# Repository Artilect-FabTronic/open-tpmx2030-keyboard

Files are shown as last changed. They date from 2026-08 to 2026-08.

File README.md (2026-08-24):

# open-tpmx2030-keyboard

Bienvenue sur le dépôt du projet de clavier BEPO `open-tpmx2030-keyboard` du FabLab Artilect.

Inspirée par la [présentation du projet ToucheLibre faite par Lilian Tribouilloy le 9 mars 2020 au fablab Artilect](https://touchelibre.fr/index.php/presentation-projet-en-video/) de Toulouse pendant l’une des soirées SuperLundi.

Ce projet a pour objectif de concevoir un clavier mécanique open source simple, basé sur le modèle de [clavier TypeMatrix 2030](https://typematrix.com/fr/products/2030/), avec des touches Cherry MX2A et des keycaps personnalisables.

Pour plus de détails sur la disposition bépo, veuillez consulter le wiki : <https://bepo.fr/wiki/TypeMatrix>

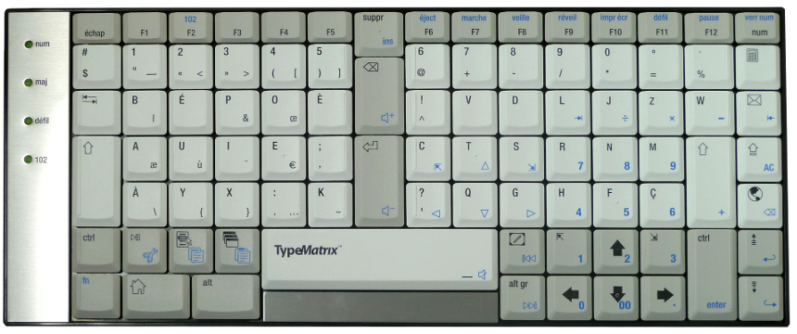
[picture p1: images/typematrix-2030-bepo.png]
TypeMatrix 2030 Bépo layout


---

## Contribuer au projet

Afin de permettre à chacun de contribuer à la version 1.0.0 du clavier `open-tpmx2030-keyboard`, merci de respecter la règle de nommage des branches et de ne pas commiter directement sur la branche main. En effet, la branche main est protégée et toute contribution doit passer par une pull request.

Un grand merci à tous les futurs contributeurs qui participeront à ce projet et qui continueront à le faire évoluer.

---

## Organisation du projet

Le présent fichier `README.md` est le point d'entrée du projet.

Le projet est structuré en différentes branches de la manière suivante :

- `feature/pcb` : contient les fichiers de conception du PCB du clavier.
- `feature/firmware` : contient le firmware du clavier.

Le dossier [`*/docs/`](./docs/README.md) : contient la documentation du projet.

Voir les bonnes pratiques pour les messages de commit : <https://commitizen-tools.github.io/commitizen/tutorials/writing_commits/>

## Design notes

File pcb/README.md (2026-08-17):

# 🛠️ Guide de Conception KiCad — Projet Open-TPMX2030

Ce guide est destiné aux membres et hackers du FabLab Artilect participant au développement de la carte électronique (PCB) du clavier ergonomique Open-TPMX2030.

Il regroupe les règles de l'art en ingénierie électronique pour concevoir un PCB propre, robuste, facile à fabriquer (JLCPCB / PCBWay) et à déboguer.

---

## 📌 1. Structure du Projet & Conventions de Nommage

Editer le fichier `.kicad_pro` avec un éditeur de texte est modifier la section `text_variables` en fin du fichier avec les éléments suivants :

```plaintext
  "text_variables": {
    "COMPANY": "Copyright (c) 2026 Artilect FabLab Toulouse",
    "CREATION_DATE": "2026-08-16",
    "LICENSE": "Apache-2.0 license",
    "PROJECT_NAME": "Open-TPMX2030 keyboard",
    "REVISION": "1.0.0",
    "SERIAL_NUM": "S/N: 260816-Artilect-P001",
    "USER_EMAIL": "arnauld.biganzoli@gmail.com",
    "USER_NAME": "ArnauldDev"
  },
```

Et depuis l'édition des fichiers `.kicad_sch` et `.kicad_pcb`, compléter la section `title_block` avec les éléments suivants :

```plaintext
	(title_block
		(title "${PROJECT_NAME}")
		(date "${CREATION_DATE}")
		(rev "${REVISION}")
		(company "${COMPANY}")
		(comment 1 "License: ${LICENSE}")
		(comment 2 "${USER_EMAIL}")
		(comment 3 "${USER_NAME}")
		(comment 4 "Electrical CAD Operator:")
	)
```

### 1.1 Organisation du Dépôt Git

Tout le projet Hardware réside dans le dossier `/pcb` du dépôt GitHub `open-tpmx2030-keyboard`.

```plaintext
├── pcb/
│   ├── open_tpmx2030.kicad_pro       # Fichier projet KiCad
│   ├── open_tpmx2030.kicad_sch       # Schématique racine (Feuille Principale)
│   ├── open_tpmx2030.kicad_pcb       # Layout du PCB
│   ├── open_tpmx2030.kicad_dru       # Règles de routage personnalisées (DRC)
│   ├── mcu_rp2040.kicad_sch          # Module Microcontrôleur RP2040-Zero
│   ├── matrix_expanders.kicad_sch    # Module MCP23017 (I2C)
│   ├── key_matrix.kicad_sch          # Matrice de switches (keyboard 102 touches + diodes)
│   ├── user_interface.kicad_sch      # Encodeurs + LEDs
│   └── libraries/                    # Symboles et Empreintes spécifiques
│       ├── symbols/                  # .kicad_sym (.kicad_sym)
│       ├── footprints/               # .kicad_mod (.pretty)
│       └── 3dmodels/                 # Modèles 3D (.3dshapes, .stp)
└── manufacturing/                    # Gerbers, Drill, BOM, CPL (Générés)
```

### 1.2 Règles de nommage des composants

Pour s'y retrouver facilement lors du soudage manuel ou de l'inspection :

* U1, U2, ... : Circuits intégrés (RP2040, MCP23017)
* SW1 à SW102 : Switches de touches (Cherry MX2A)
* SW_ENC1 à SW_ENC3 : Switches d'encodeurs rotatifs
* D1 à D102 : Diodes de matrice (1N4148 / SOD-123)
* LED1 à LED4 : LEDs d'état (0805)
* R1, R2, ... : Résistances
* C1, C2, ... : Condensateurs
* ENC1 à ENC3 : Encodeurs rotatifs (EC11)

---

## 📐 2. La schématique (Eeschema)

### 2.1 Approche par Schémas Hiérarchiques

Ne mettez jamais l'intégralité d'un projet de 102 touches sur une seule page géante !

Utilisez des Feuilles Hiérarchiques (Hierarchical Sheets) :

1. Racine (open_tpmx2030.kicad_sch) : Bloc-diagramme reliant les sous-modules via des labels hiérarchiques (Bus I2C, INT, Power).
2. Feuille mcu_rp2040 : RP2040-Zero, régulateur de tension (si besoin), filtrage d'alimentation, connecteur USB-C.
3. Feuille matrix_expanders : Les 2x MCP23017, adresses I2C (A0, A1, A2), résistances de tirage I2C (Pull-up).
4. Feuille key_matrix : Matrice $8 \times 13$ réparties proprement en sous-ensembles (ex: réplication de blocs).
5. Feuille user_interface : 3 Encodeurs EC11 + 4 LEDs.

### 2.2 Bonnes Pratiques de Schématique

* **Sens de lecture :** Les signaux d'entrée viennent de la **gauche**, les sorties vont vers la **droite**, les alimentations ($V_{CC}$ / $+3.3\text{V}$) sont en **haut**, et les masses ($\text{GND}$) sont en **bas**.
* **Condensateurs de découplage :** Dessinez TOUJOURS les condensateurs de découplage ($100\text{ nF}$) à côté des broches d'alimentation des puces correspondantes (`VCC/VDD` du MCP23017, etc.) sur le schéma, pour rappeler qu'ils doivent être soudés au plus près en layout.
* **Net Labels clairs :** Utilisez des noms de réseaux explicites (`I2C_SDA`, `I2C_SCL`, `ROW_0`, `COL_12`, `ENC_VOL_CLK`).

---

## ⚡ 3. Les Règles de Routage PCB (Pcbnew)

### 3.1 Empilement de la Carte (Layer Stackup - 2 Couches)

Puisqu'il s'agit d'une carte 2 couches classique (1.6 mm FR4, $35\ \mu\text{m}$ Cuivre) :

* Couche Supérieure (F.Cu - Red) : Signaux principaux, bus de données, matrice de touches.
* Couche Inférieure (B.Cu - Blue) : Plan de Masse Continu ($\text{GND}$).
  * _Règle absolue :_ Évitez au maximum de couper le plan de masse face inférieure avec de longues pistes. Si une piste doit passer en `B.Cu`, faites un "pont" court et revenez en `F.Cu`.

### 3.2 Largeur de Pistes (Track Widths)

Configurons les classes de réseaux (Net Classes) dans KiCad :

| Classe de Réseau | Largeur de Piste | Isolation (Clearance) | Via (Perçage / Anneau) | Usage |
| --- | --- | --- | --- | --- |
| Default | $0.20\text{ mm}$ ($8\text{ mil}$)  | $0.20\text{ mm}$ ($8\text{ mil}$)  | $0.6\text{ mm} / 0.3\text{ mm}$ | Signaux matrice, LEDs, GPIOs |
| HighSpeed_I2C | $0.25\text{ mm}$ ($10\text{ mil}$) | $0.25\text{ mm}$ ($10\text{ mil}$) | $0.6\text{ mm} / 0.3\text{ mm}$ | Bus I2C (SDA / SCL à 1 MHz) |
| Power (+3.3V) | $0.50\text{ mm}$ ($20\text{ mil}$) | $0.25\text{ mm}$ ($10\text{ mil}$) | $0.8\text{ mm} / 0.4\text{ mm}$ | Lignes d'alimentation principal |
| Power (+5V USB)  | $0.75\text{ mm}$ ($30\text{ mil}$) | $0.30\text{ mm}$ ($12\text{ mil}$) | $0.8\text{ mm} / 0.4\text{ mm}$ | VBUS d'entrée USB |

### 3.3 Placement des Composants

1. **Positionnement Ergonomique (Fixe) :** Placez d'abord les switches MX2A (espacement standard $19.05\text{ mm} \times 19.05\text{ mm}$ ou selon le layout spécifique TypeMatrix), les 3 encodeurs et les 4 LEDs.
2. **Zone Microcontrôleur & Expanders :** Placez le RP2040-Zero et les 2x MCP23017 dans la partie supérieure de la carte.
3. **Condensateurs de découplage ($100\text{ nF}$) :** Placer IMPÉRATIVEMENT chaque condensateur de découplage à moins de $2\text{ mm}$ de la broche $V_{DD}$ du MCP23017, relié directement au plan de masse par un via.

---

## 🛡️ 4. Intégrité du Signal & Compatibilité Électromagnétique (CEM)

1. **Bus I2C à 1 MHz :**
  * Gardez les pistes I2C_SDA et I2C_SCL parallèles, de longueur similaire et le plus court possible entre le RP2040-Zero et les deux MCP23017.
  * Placez les résistances de tirage ($R_{pullup} = 2.2\text{ k}\Omega$) près du RP2040-Zero.
2. **Diodes Anti-Ghosting :**
  * Chaque touche contient une diode 1N4148 (boîtier SOD-123). Placez la diode juste à côté du pad du switch correspondant pour garder un routage ultra-propre et compact.
3. **Vias de Masse (Via Stitching) :**
  * Distribuez généreusement des vias de masse autour du microcontrôleur et le long du contour de la carte pour assurer une excellente continuité du plan de masse GND.

---

## 🔍 5. Liste de Contrôle Avant Fabrication (Checklist DRC)

Avant de générer les fichiers Gerber pour le FabLab ou l'usine :

- [ ] Lancer le DRC (Design Rules Check) : 0 erreur, 0 avertissement toléré.
- [ ] Contrôle d'empreintes (Footprints) : Vérifier le sens des diodes (Cathode / Anode) et l'orientation du RP2040-Zero.
- [ ] Trous de Fixation (Mounting Holes) : Placer des trous $M3$ (non métallisés ou reliés à la masse) aux 4 coins et au centre pour la rigidité lors de la frappe.
- [ ] Visualisation 3D (Alt + 3) : Vérifier qu'aucun composant ne se chevauche (notamment les corps des switches MX2A et les encodeurs EC11).
- [ ] Sérigraphie (Silkscreen) :
  * Nom du projet : Open-TPMX2030 (FabLab Artilect)
  * Version du PCB : v1.0.0 - 2026
  * Logos : Logo Open Source Hardware + Logo Artilect.
  * Indication lisible des LEDs (NUM/FN, CAPS, SCROLL, DVORAK) et des fonctions des encodeurs (LUM, MIC, VOL).

---

## 📦 6. Export pour la Fabrication

Exportez depuis KiCad dans le dossier `/production` :

1. **Fichiers Gerber (RS-274X) :** Couches `F.Cu`, `B.Cu`, `F.Silkscreen`, `B.Silkscreen`, `F.Mask`, `B.Mask`, `Edge.Cuts` (Contour).
2. **Fichier de Perçage (Excellon / NC Drill) :** Unités en mm, coordonnées absolues.
3. **Fichiers de Placement SMT (Position / CPL) :** Fichier `.csv` pour l'assemblage automatique des composants de surface (Diodes SOD-123, MCP23017, Résistances 0805).

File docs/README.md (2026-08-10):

# Documentation Technique — Open-TPMX2030

> Étude technique du projet de conception du clavier **Open-TPMX2030**  
> *(Open Source TypeMatrix Mechanical Edition)*  
> Projet du FabLab **Artilect** — Toulouse

---

## Table des matières

| N°  | Document | Description |
| --- | --- | --- |
| — | [Présentation du projet](./01-presentation-projet.md) | Genèse, objectifs, organisation du dépôt  |
| — | [Conception Hardware & PCB](./02-conception-hardware.md) | MCU, matrice de touches, BOM, pinout |
| — | [Interface Homme-Machine (IHM)](./03-interface-ihm.md) | Encodeurs rotatifs, LEDs, keycaps |
| — | [Architecture Firmware](./04-firmware-architecture.md) | Code C++/Arduino, HID, scancodes |
| — | [Analyse GPIO & Extension I2C](./05-analyse-gpio-extension.md) | MCP23017 vs 74HC165, architecture retenue |
| — | [Dispositions Clavier](./06-dispositions-clavier.md) | Bépo, Dvorak, QWERTY, outils logiciels |
| — | [Ressources & Références](./07-ressources-references.md) | Datasheets, liens, fournisseurs, projets  |

---

## Architecture Globale du Projet

```mermaid
graph TD
    subgraph HARDWARE["🔧 Hardware (PCB)"]
        MCU["RP2040-Zero\n(ARM Cortex-M0+)"]
        MCP1["MCP23017 #1\n(Lignes - 0x20)"]
        MCP2["MCP23017 #2\n(Colonnes - 0x21)"]
        MATRIX["Matrice 8×13\n(102 switches + 1N4148)"]
        ENC["3× Encodeurs EC11\n(Luminosité / Micro / Volume)"]
        LEDS["4× LEDs SMD 0805\n(Num / Caps / Scroll / Dvorak)"]
    end

    subgraph FIRMWARE["💾 Firmware (Arduino / C++)"]
        SCAN["Scan Matrice I2C"]
        MAP["Mapping Scancodes\n(HID ↔ PS/2)"]
        HID["Rapport USB HID\n(Keyboard + Consumer)"]
        LAYOUTS["Couches de Layout\nQWERTY / Bépo / Dvorak"]
    end

    subgraph HOST["🖥️ Hôte USB"]
        USB["Port USB-C\n(HID Device)"]
        PC["Ordinateur"]
    end

    MCU -- "I2C 1 MHz\n(SDA/SCL GP2/GP3)" --> MCP1
    MCU -- "I2C 1 MHz" --> MCP2
    MCP1 -- "Port A (L0-L7)\nOUT" --> MATRIX
    MCP2 -- "Port A+B (C0-C12)\nIN Pull-up" --> MATRIX
    MCU -- "GP7-GP15\n(CLK/DT/SW)" --> ENC
    MCU -- "GP0, GP4-GP6" --> LEDS
    MCU -- "INT GP1\n(Wake-up)" --> MCP1

    SCAN --> MAP --> LAYOUTS --> HID
    MCU --> SCAN
    HID --> USB --> PC
```

---

## Résumé Technique Rapide

| Caractéristique | Valeur |
| --- | --- |
| **Microcontrôleur** | Waveshare RP2040-Zero (ARM Cortex-M0+ @ 133 MHz) |
| **Nombre de touches** | 102 touches (layout 102 Europe) |
| **Extension GPIO** | 2× MCP23017 sur bus I2C @ 1 MHz |
| **Latence scan matrice** | < 300 µs (invisible à la frappe) |
| **Switches V1** | Cherry MX2A Brown (Tactile) |
| **Switches V2** | Cherry MX2A Blue (Clicky) |
| **Anti-ghosting** | Full N-Key Rollover (NKRO) via diodes 1N4148 |
| **IHM** | 3 encodeurs EC11 + 4 LEDs d'état |
| **Firmware** | Arduino-Pico (Earle F. Philhower) |
| **Interface USB** | USB HID natif (Keyboard + Consumer Control) |
| **Layouts supportés** | QWERTY, Bépo, Dvorak, Colemak-DH |
| **Licence** | Apache-2.0 license (Open Source) |

---

## Image de référence du Layout

TypeMatrix 2030 Bépo layout

---

## Liens Rapides

- 🏠 [Dépôt GitHub principal](https://github.com/Artilect-FabTronic/open-tpmx2030-keyboard)
- 📋 [Wiki Bépo — TypeMatrix](https://bepo.fr/wiki/TypeMatrix)
- 🔌 [Datasheet RP2040](https://pip-assets.raspberrypi.com/categories/814-rp2040/documents/RP-008371-DS-1-rp2040-datasheet.pdf)
- 🔌 [Datasheet MCP23017](https://ww1.microchip.com/downloads/aemDocuments/documents/APID/ProductDocuments/DataSheets/MCP23017-MCP23S17-16-Bit-IO-Expander-with-Serial-Interface-DS20001952.pdf)
- 🛠️ [KiCad — Logiciel PCB](https://www.kicad.org/)
- ⌨️ [Configurateur Keycaps ThockFactory](https://thockfactory.com/fr/configurator)

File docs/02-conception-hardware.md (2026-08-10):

# 02 — Conception Hardware & PCB

> **Retour à l'index :** [Documentation](./README.md)

---

## Table des matières

- [Microcontrôleur — RP2040-Zero](#microcontrôleur--rp2040-zero)
- [Matrice de touches](#matrice-de-touches)
- [Switches Cherry MX2A](#switches-cherry-mx2a)
- [Assignation finale des broches GPIO](#assignation-finale-des-broches-gpio)
- [Architecture hardware globale](#architecture-hardware-globale)
- [Nomenclature BOM](#nomenclature-bom)
- [Outils de conception PCB](#outils-de-conception-pcb)

---

## Microcontrôleur — RP2040-Zero

### Pourquoi le RP2040 ?

Le **RP2040** de Raspberry Pi a été retenu comme cœur du projet pour les raisons suivantes :

- **Dual-core ARM Cortex-M0+** cadencé à 133 MHz — puissance largement suffisante pour la gestion d'un clavier complexe.
- **Support natif USB HID** : pas de circuit USB externe requis, le RP2040 gère lui-même le protocole USB Full Speed.
- **Écosystème open source vaste** : SDK C/C++, MicroPython, CircuitPython, Arduino-Pico.
- **Faible coût** (~3-5 € l'unité en lot).
- **Format castellated** du RP2040-Zero : permet de souder directement la carte sur le PCB principal.

### Caractéristiques techniques du RP2040-Zero (Waveshare)

| Caractéristique | Valeur |
| --- | --- |
| **Processeur** | ARM Cortex-M0+ dual-core @ 133 MHz |
| **SRAM** | 264 Ko |
| **Mémoire Flash** | 2 Mo (W25Q16 SOIC-8) |
| **GPIO accessibles** | 20 broches (GP0–GP15, GP26–GP29) |
| **Connectique** | USB-C |
| **Spécificité** | Format ultra-compact, castellated (soudable sur PCB) |
| **LED RGB intégrée** | WS2812B sur GPIO 16 |

### Ressources

- 📄 [Datasheet RP2040](https://pip-assets.raspberrypi.com/categories/814-rp2040/documents/RP-008371-DS-1-rp2040-datasheet.pdf)
- 📄 [Hardware Design with RP2040](https://pip-assets.raspberrypi.com/categories/814-rp2040/documents/RP-008279-DS-1-hardware-design-with-rp2040.pdf)
- 🌐 [Wiki Waveshare RP2040-Zero](https://www.waveshare.com/wiki/RP2040-Zero)
- 🔌 [Pinout TinyGo Reference](https://tinygo.org/docs/reference/microcontrollers/machine/waveshare-rp2040-zero/)

### Pinout et schématique de la carte RP2040-Zero

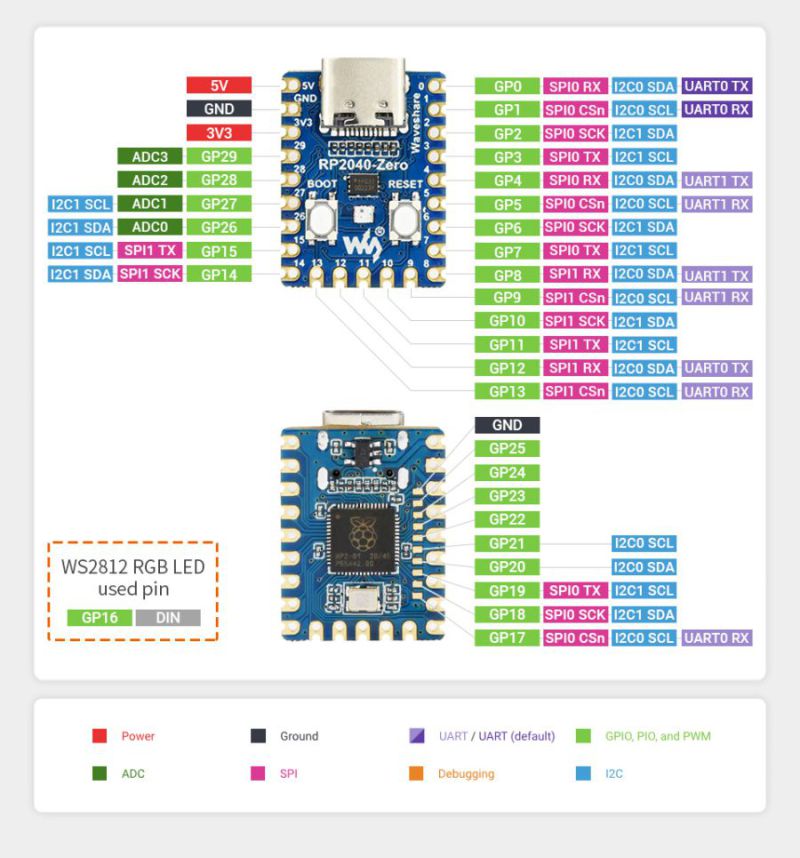
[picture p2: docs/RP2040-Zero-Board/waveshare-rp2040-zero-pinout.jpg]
Waveshare RP2040-Zero Pinout


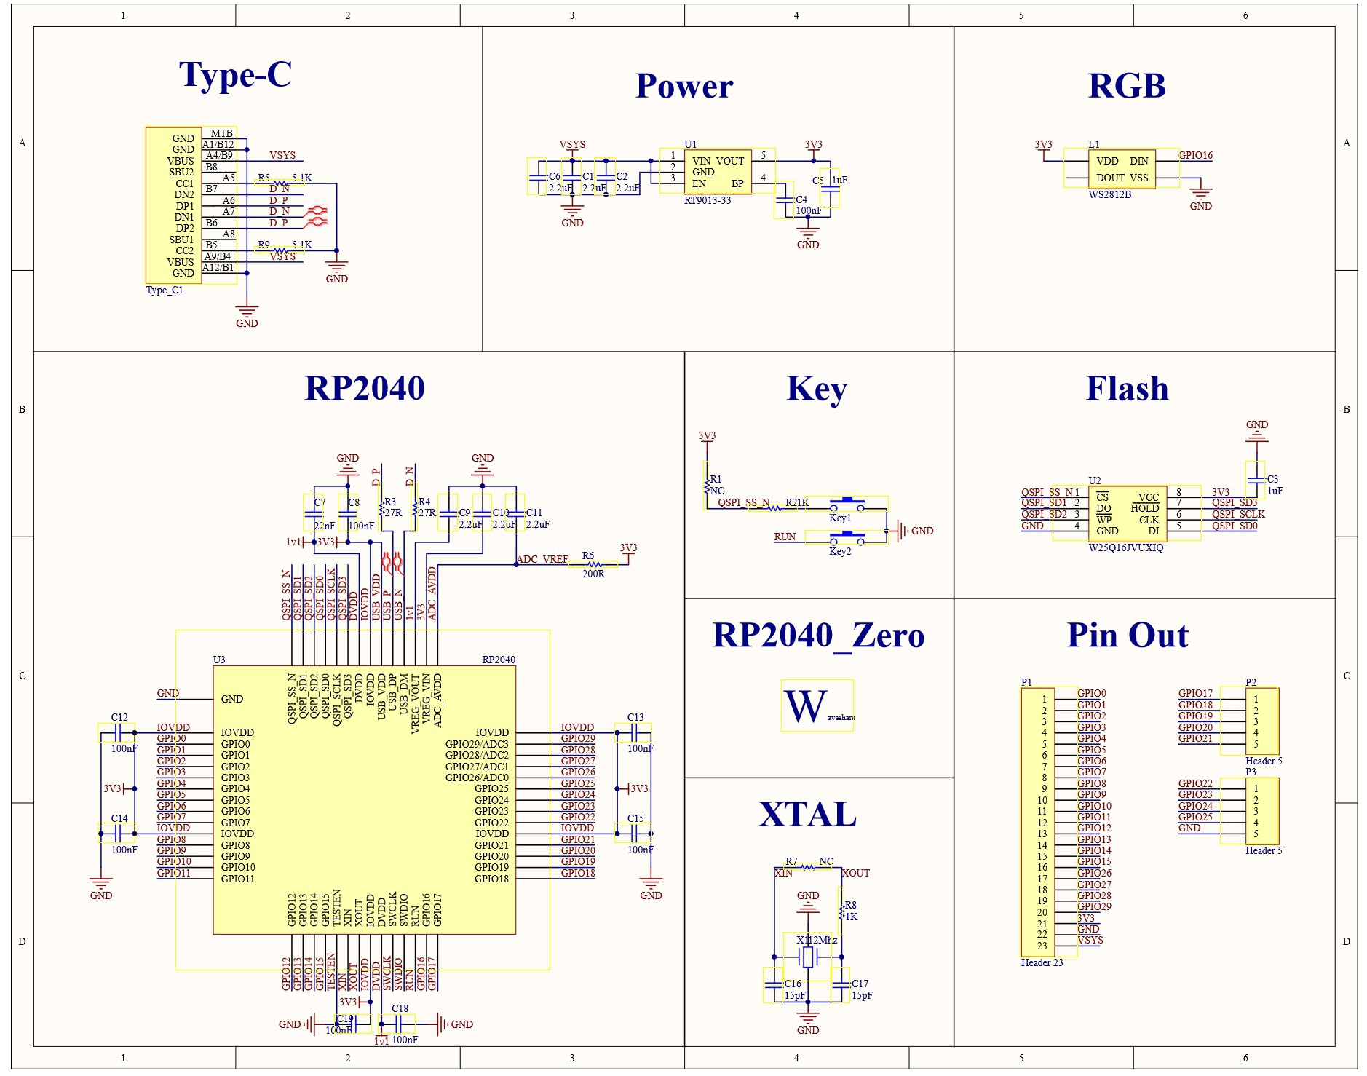
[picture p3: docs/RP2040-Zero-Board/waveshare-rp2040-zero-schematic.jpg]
Waveshare RP2040-Zero Schéma


### Options de programmation

| Environnement | Langage | Remarques |
| --- | --- | --- |
| **Arduino-Pico** (Earle Philhower) | C++ | Retenu pour ce projet — support HID natif |
| SDK officiel Raspberry Pi | C/C++ | Plus bas niveau, plus de contrôle |
| MicroPython | Python  | Moins adapté pour HID temps-réel |
| CircuitPython (Adafruit) | Python  | Bonne bibliothèque HID |

**Pour ajouter le support RP2040 dans Arduino IDE**

Additional Boards Manager URLs : `https://github.com/earlephilhower/arduino-pico/releases/download/global/package_rp2040_index.json`

---

## Matrice de touches

### Principe de la matrice

La matrice de touches est la solution standard pour connecter un grand nombre de touches avec un minimum de broches. Les touches sont organisées en **lignes** et **colonnes** ([vidéo](https://www.youtube.com/watch?v=dop0SoD2XL8)) :

- Une seule **ligne** est activée à la fois (mise à LOW).
- Toutes les **colonnes** sont lues simultanément.
- Une **diode par touche** (1N4148) évite le phénomène de *ghosting* (touches fantômes) et permet le **N-Key Rollover (NKRO)** — détection simultanée de toutes les touches.

### Dimensions de la matrice

Pour 102 touches, la topologie retenue est :

```
8 Lignes (Output) × 13 Colonnes (Input Pull-up) = 104 emplacements
```

> Les 2 emplacements non utilisés peuvent être réservés pour des touches supplémentaires futures.

### Diodes Anti-Ghosting

- **Référence :** 1N4148 (boîtier SOD-123 pour montage CMS)
- **Câblage :** Anode → Ligne, Cathode → Colonne (via le switch)
- **Effet :** Full N-Key Rollover — appui simultané de toutes les touches sans ambiguïté.

```
    Ligne (LOW)
        |
       [A]→[K]→[1N4148]→ Colonne (IN Pull-up)
       [A] = Anode diode
       [K] = Cathode diode
       [1N4148] = Diode
```

### Pourquoi pas de GPIO directs sur le RP2040 ?

Le RP2040-Zero n'expose que **20 broches GPIO**. Avec les périphériques déjà connectés (LEDs, encodeurs), il ne reste que **7 GPIO libres**, insuffisants pour piloter 21 lignes/colonnes. L'extension via **MCP23017** (I2C) est donc indispensable.

> Pour l'analyse complète de ce choix, voir : [05 — Analyse GPIO & Extension I2C](./05-analyse-gpio-extension.md)

---

## Switches Cherry MX2A

### Version V1 — Brown (Tactile)

- **Référence :** [Cherry MX2A Brown](https://www.cherry.de/en-gb/product/mx2a-brown)
- **Type :** Tactile, pré-lubrifié d'usine
- **Caractéristiques :** Frappe fluide et relativement silencieuse, retour tactile subtil
- **Usage recommandé :** Environnements de bureau, frappe intensive

### Version V2 — Blue (Clicky)

- **Référence :** [Cherry MX2A Blue](https://www.cherry.de/en-gb/product/mx2a-blue)
- **Type :** Clicky, retour tactile accentué avec clic sonore
- **Usage recommandé :** Utilisateurs appréciant le feedback sonore

### Sockets Hotswap

Recherche en cours d'un support de touche **soudable sur PCB** permettant l'échange des switches Cherry MX2A sans dessouder.

- Compatibilité : Cherry MX (standard 5mm stem spacing)
- Références à valider : Kailh PCB Socket, Mill-Max 0305 / 7305

> **Fournisseurs :** [RS-Online — Interrupteurs clavier](https://fr.rs-online.com/web/p/interrupteurs-de-clavier/0664569) | [Mouser — Cherry Electrical](https://www.mouser.fr/fr/manufacturer/cherry-electrical/)

---

## Assignation finale des broches GPIO

Cette table intègre l'ensemble des périphériques connectés au RP2040-Zero :

| Fonction | Pin RP2040-Zero | Direction  | Rôle |
| --- | --- | --- | --- |
| **I2C SDA** | GP2 | Bidir | Bus données I2C (MCP23017 #1 & #2) |
| **I2C SCL** | GP3 | OUT | Bus horloge I2C @ 1 MHz |
| **INT_KEYBOARD** | GP1 | IN Pull-up | Interruption matrice / Wake-Up sommeil |
| **LED 1 (Num/Fn)** | GP0 | OUT | LED état — Couleur bleue |
| **LED 2 (Caps)** | GP4 | OUT | LED Caps Lock |
| **LED 3 (Scroll)** | GP5 | OUT | LED Scroll Lock |
| **LED 4 (Dvorak)** | GP6 | OUT | LED Mode Dvorak |
| **Enc 1 CLK (Lum)** | GP7 | IN Pull-up | Luminosité — Signal horloge |
| **Enc 1 DT (Lum)** | GP8 | IN Pull-up | Luminosité — Signal direction |
| **Enc 1 SW (Lum)** | GP9 | IN Pull-up | Luminosité — Bouton poussoir |
| **Enc 2 CLK (Mic)** | GP10 | IN Pull-up | Microphone — Signal horloge |
| **Enc 2 DT (Mic)** | GP11 | IN Pull-up | Microphone — Signal direction |
| **Enc 2 SW (Mic)** | GP12 | IN Pull-up | Microphone — Bouton poussoir |
| **Enc 3 CLK (Vol)** | GP13 | IN Pull-up | Volume — Signal horloge |
| **Enc 3 DT (Vol)** | GP14 | IN Pull-up | Volume — Signal direction |
| **Enc 3 SW (Vol)** | GP15 | IN Pull-up | Volume — Bouton poussoir |
| **LED RGB (NeoPixel)** | GP16 | OUT | LED RGB intégrée (WS2812B) |
| **Disponibles** | GP26, GP27, GP28, GP29 | Libre | PWM rétroéclairage, extensions futures |

### Bilan GPIO

| Catégorie | GPIOs utilisées |
| --- | --- |
| Bus I2C (SDA + SCL)  | 2 |
| Interruption Wake-up | 1 |
| LEDs d'état | 4 |
| Encodeurs (3 × 3) | 9 |
| **Total utilisé** | **16 / 20** |
| **Libres** | **4 (GP26–GP29)** |

---

## Architecture hardware globale

```
                       RP2040-ZERO
                   +-----------------+
                   | GP2 (SDA) ------+----------> Bus I2C (SDA) + Pull-up 2.2kΩ
                   | GP3 (SCL) ------+----------> Bus I2C (SCL) + Pull-up 2.2kΩ
                   | GP1 (INT_WAKE) -+<---------- INTA (Combined Interrupt)
                   | GP0  (LED Num) -+----------> LED SMD 0805 Bleue
                   | GP4  (LED Caps)-+----------> LED SMD 0805
                   | GP5  (LED Scrl)-+----------> LED SMD 0805
                   | GP6  (LED Dvk) -+----------> LED SMD 0805
                   | GP7-9  (Enc 1) -+----------> Encodeur Luminosité EC11
                   | GP10-12 (Enc 2)-+----------> Encodeur Microphone EC11
                   | GP13-15 (Enc 3)-+----------> Encodeur Volume EC11
                   +-----------------+
                            |
           +----------------+----------------+
           |                                 |
  +-----------------+               +-----------------+
  |   MCP23017 #1   |               |   MCP23017 #2   |
  |  Adresse: 0x20  |               |  Adresse: 0x21  |
  +-----------------+               +-----------------+
  | Port A: Lignes  |               | Port A: Col 0-7 |
  | (L0 - L7) OUT   |               | Port B: Col 8-12|
  +-----------------+               +-----------------+
           |                                 |
           +------------ Matrice ------------+
                    (102 Switches + 1N4148)
                    8 Lignes × 13 Colonnes
```

---

## Nomenclature BOM

*Bill of Materials — Nomenclature préliminaire du projet*

| Désignation | Référence / Modèle | Qté | Boîtier | Remarques |
| --- | --- | ----- | --- | --- |
| **Microcontrôleur** | Waveshare RP2040-Zero  | 1 | Module | Format castellated, USB-C intégré |
| **Extenseur GPIO** | MCP23017-E/SS | 2 | SSOP-28 | Bus I2C, adresses 0x20 et 0x21 |
| **Mémoire Flash** | W25Q16 / W25Q32 | 1 | SOIC-8 | Embarquée sur le RP2040-Zero |
| **Switches Mec.** | Cherry MX2A Brown (V1) | ~102  | Traversant | V1 — Tactile |
| **Switches Mec.** | Cherry MX2A Blue (V2)  | ~102  | Traversant | V2 — Clicky |
| **Diodes Anti-Ghost.** | 1N4148W | ~102  | SOD-123 | 1 par switch — NKRO |
| **Encodeurs Rotatifs** | EC11 avec switch | 3 | Traversant | Luminosité, Micro, Volume |
| **LED Signalisation**  | LED SMD 0805 Bleue | 1 | 0805 | Num/Fn Lock |
| **LED Signalisation**  | LED SMD 0805 | 3 | 0805 | Caps, Scroll, Dvorak |
| **Connecteur USB** | USB Type-C Réceptacle  | 1 | SMD | Alimentation & Data HID |
| **Résistances I2C** | 2.2kΩ | 2 | 0402 | Pull-up SDA et SCL |
| **Condensateurs** | 100nF | ~10 | 0402 | Découplage alimentation |
| **Condensateurs** | 10µF | 2 | 0805 | Filtrage alimentation principale |
| **Keycaps Set** | Custom Ortholinear | 1 set | — | Marquages Bépo/Dvorak/QWERTY (ThockFactory) |
| **Sockets Hotswap** | Kailh PCB Socket (TBC) | ~102  | SMD | À confirmer — compatibilité Cherry MX |

---

## Outils de conception PCB

### KiCad

Le PCB est conçu sous [**KiCad**](https://www.kicad.org/) (version 10+), logiciel EDA open source.

- **Schématique (Schéma électrique)** : KiCad Schematic Editor (`.kicad_sch`)
- **PCB Layout** : KiCad PCB Editor (`.kicad_pcb`)
- **Empreintes Cherry MX** : disponibles dans les bibliothèques officielles KiCad ou via [github.com/blakesmith/embedded](https://github.com/blakesmith/embedded/tree/master/keebee/hardware)

```
Empreinte 3D switch Cherry MX :
${KISYS3DMOD}/Buttons_Switches_Keyboard.3dshapes/SW_Cherry_MX1A_1.00u_Plate.wrl
```

### Ergogen (Layout PCB automatisé)

[**Ergogen**](https://ergogen.xyz/new) est un outil web permettant de générer automatiquement la disposition physique des touches et le PCB à partir d'un fichier de configuration YAML. Particulièrement adapté aux claviers ortholinéaires.

---

> **Page précédente :** [01 — Présentation du projet](./01-presentation-projet.md)  
> **Page suivante :** [03 — Interface Homme-Machine (IHM)](./03-interface-ihm.md)

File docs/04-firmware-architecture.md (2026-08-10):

# 04 — Architecture Firmware

> **Retour à l'index :** [Documentation](./README.md)

---

## Table des matières

- [Choix de l'environnement de développement](#choix-de-lenvironnement-de-développement)
- [Boucle principale du firmware](#boucle-principale-du-firmware)
- [USB HID — Protocole et implémentation](#usb-hid--protocole-et-implémentation)
- [Traduction Scancodes USB HID ↔ PS/2](#traduction-scancodes-usb-hid--ps2)
- [Gestion des layouts alternatifs](#gestion-des-layouts-alternatifs)
- [Code source complet commenté](#code-source-complet-commenté)

---

## Choix de l'environnement de développement

### Arduino-Pico (Earle F. Philhower)

Le firmware est développé sous [**Arduino-Pico**](https://github.com/earlephilhower/arduino-pico) — le core Arduino non-officiel mais très complet pour le RP2040, maintenu par Earle F. Philhower.

**Pourquoi Arduino-Pico plutôt que QMK ou ZMK ?**

| Critère | Arduino-Pico | QMK | ZMK |
| --- | --- | --- | --- |
| **Flexibilité totale** | ✅ Accès complet bas niveau | ⚠️ Abstrait  | ⚠️ Abstrait |
| **Support RP2040-Zero** | ✅ Natif | ⚠️ Limité | ❌ Peu supporté |
| **USB HID natif** | ✅ TinyUSB intégré | ✅ | ✅ |
| **Sur-mesure** | ✅ Total | ⚠️ Configuré | ⚠️ Configuré |
| **Courbe d'apprentissage** | Modérée (C++) | Modérée | Élevée (Zephyr RTOS) |
| **Bibliothèques Arduino**  | ✅ Compatibles | ❌ | ❌ |

### Installation

1. Ouvrir Arduino IDE
2. Aller dans **Fichier → Préférences → URL de gestionnaire de cartes supplémentaires**
3. Ajouter :
   ```
   https://github.com/earlephilhower/arduino-pico/releases/download/global/package_rp2040_index.json
   ```
4. **Outils → Type de carte → Gestionnaire de cartes** → Rechercher "RP2040" → Installer

### Dépendances

```cpp
#include <Arduino.h>
#include <Wire.h>           // Bus I2C pour MCP23017
#include <Adafruit_TinyUSB.h> // Stack USB HID (TinyUSB)
```

Bibliothèque de référence :  
📦 [github.com/earlephilhower/arduino-pico/libraries/Keyboard](https://github.com/earlephilhower/arduino-pico/tree/master/libraries/Keyboard)

---

## Boucle principale du firmware

La logique du firmware suit un cycle simple et déterministe, exécuté en continu :

```
┌─────────────────────────────────────────────────────┐
│                   BOUCLE PRINCIPALE                 │
│                    (toutes ~1 ms)                   │
│                                                     │
│  1. TinyUSBDevice.task()  ← Traitement USB          │
│  2. scanMatrixI2C()       ← Lecture matrice MCP     │
│  3. readEncoders()        ← Lecture encodeurs EC11  │
│  4. updateLEDs()          ← Mise à jour LEDs        │
│  5. delay(1)              ← Stabilisation boucle    │
└─────────────────────────────────────────────────────┘
```

### Algorithme de balayage détaillé

```
Pour chaque ligne (0 → 7) :
  1. Écrire sur MCP23017 #1 : activer la ligne courante (LOW)
  2. Lire MCP23017 #2 : état des 13 colonnes (Port A + Port B)
  3. Pour chaque colonne (0 → 12) :
     a. Comparer l'état actuel avec l'état précédent
     b. Si changement détecté → appliquer anti-rebond
     c. Si touche pressée → mapper sur le scancode HID via la table active
     d. Si touche relâchée → retirer le scancode du rapport HID
  4. Désactiver la ligne (HIGH)
  5. Envoyer le rapport HID si modification
```

---

## USB HID — Protocole et implémentation

### Présentation du protocole HID

L'**USB HID** (Human Interface Device) est la norme USB permettant à un clavier de communiquer avec un hôte (ordinateur). Le clavier envoie des **rapports** (reports) à l'hôte à intervalles réguliers.

#### Rapport HID clavier standard (Boot Protocol)

```
Byte 0 : Modificateurs (Shift, Ctrl, Alt, Win...)
Byte 1 : Réservé (0x00)
Bytes 2-7 : Keycodes actifs (jusqu'à 6 touches simultanées)
```

#### Rapport HID NKRO (N-Key Rollover)

En mode NKRO, le rapport HID contient un **bitmap de 256 bits** (32 octets) représentant l'état de chaque touche possible, permettant la détection simultanée de toutes les touches.

### Taux de rapport (Polling Rate)

- **Standard USB FS :** 125 Hz (8 ms de latence max)
- **High-speed (recommandé) :** 1000 Hz (1 ms de latence max)
- **Configuration TinyUSB :**
  ```cpp
  usbHid.setPollInterval(1); // 1 ms = 1000 Hz
  ```

### Consumer Control (encodeurs)

Les fonctions volume et microphone utilisent les **Consumer Controls USB HID** (page 0x0C) :

| Fonction | Usage ID HID | Page |
| --- | --- | --- |
| Volume Increment | 0x00E9 | Consumer Page (0x0C)  |
| Volume Decrement | 0x00EA | Consumer Page (0x0C)  |
| Mute | 0x00E2 | Consumer Page (0x0C)  |
| Mic Mute | 0x00CF | Telephony Page (0x0B) |

### Descripteur HID

```cpp
uint8_t const desc_hid_report[] = {
  TUD_HID_REPORT_DESC_KEYBOARD(HID_REPORT_ID(1)),
  TUD_HID_REPORT_DESC_CONSUMER(HID_REPORT_ID(2))
};
```

---

## Traduction Scancodes USB HID ↔ PS/2

### Contexte

Le TypeMatrix USB-2030-B-US-DV-102 Europe utilise des **HID Usage IDs** (scancodes USB HID). Ces codes sont convertis en **scancodes PS/2 (Set 1 Make)** via la *USB HID to PS/2 Scan Code Translation Table* de Microsoft, nécessaire pour la compatibilité avec certains systèmes et firmwares.

### Principe de la table de mapping

```cpp
// Exemple de table de correspondance HID → PS/2
// Index = HID Usage ID, Valeur = PS/2 Scan Code Set 1 Make
const uint8_t hid_to_ps2_table[] = {
  0x00, // 0x00 - No Event
  0x00, // 0x01 - Keyboard ErrorRollOver
  0x00, // 0x02 - Keyboard POSTFail
  0x00, // 0x03 - Keyboard ErrorUndefined
  0x1E, // 0x04 - A
  0x30, // 0x05 - B
  0x2E, // 0x06 - C
  // ... (102 entrées)
};
```

### Tables de mapping par layout

Le firmware maintient **plusieurs tables de scancodes** correspondant aux différents layouts supportés. La commutation entre layouts se fait dynamiquement :

```cpp
// Pointeur sur la table active
const uint8_t* activeKeymap = keymap_qwerty;

// Commutation au runtime
void switchLayout(Layout_t layout) {
  switch (layout) {
    case LAYOUT_QWERTY:  activeKeymap = keymap_qwerty;  break;
    case LAYOUT_BEPO:    activeKeymap = keymap_bepo;    break;
    case LAYOUT_DVORAK:  activeKeymap = keymap_dvorak;  break;
    case LAYOUT_COLEMAK: activeKeymap = keymap_colemak; break;
  }
  modeDvorak = (layout == LAYOUT_DVORAK);
  updateLEDs();
}
```

---

## Gestion des layouts alternatifs

### Layouts supportés

| Layout | Description | Référence |
| --- | --- | --- |
| **QWERTY** | Layout standard international | — |
| **Bépo** | Layout français ergonomique (équivalent Dvorak) | [bepo.fr](https://bepo.fr) |
| **Dvorak** | Layout anglais ergonomique | [Wikipedia Dvorak](https://fr.wikipedia.org/wiki/Disposition_Dvorak) |
| **Colemak-DH** | Layout moderne ergonomique | [DreymaR EPKL](https://github.com/DreymaR/BigBagKbdTrixPKL) |

### Implémentation au niveau firmware vs OS

Deux approches existent pour implémenter les layouts alternatifs :

| Approche | Avantage | Inconvénient |
| --- | --- | --- |
| **Au niveau firmware** *(retenu)* | Indépendant de l'OS, fonctionne partout | Configuration initiale plus complexe  |
| **Au niveau OS** (XKB, MSKLC…) | Simple à déployer | Dépendant de la configuration de l'OS |

L'approche **firmware** a été retenue car elle rend le clavier autonome — le même layout est actif quel que soit l'ordinateur auquel il est connecté.

### Référence pour Colemak-DH

Le projet [**DreymaR's Big Bag of Keyboard Tricks (EPKL)**](https://github.com/DreymaR/BigBagKbdTrixPKL) est la référence pour l'implémentation du Colemak-DH et de ses variantes. Les fichiers de configuration se trouvent dans :
```
EPKL_Layouts_Default.ini
```

---

## Code source complet commenté

```cpp
#include <Arduino.h>
#include <Wire.h>
#include <Adafruit_TinyUSB.h>

/* ============================================================================
 * CONFIGURATION ET DÉFINITION DES BROCHES (RP2040-ZERO)
 * ============================================================================
 * Le RP2040-Zero dispose de 20 GPIO accessibles (GP0 à GP15, GP26 à GP29).
 * La matrice 8×13 (102 touches) est gérée via 2 MCP23017 sur le bus I2C.
 * Voir : docs/05-analyse-gpio-extension.md pour le détail du choix.
 */

// --- 1. LEDS D'ÉTAT ---
#define PIN_LED_NUM_FN    0  // LED 1 : Lock Touches / Mode Fn (Bleue)
#define PIN_LED_CAPS      4  // LED 2 : Caps Lock
#define PIN_LED_SCROLL    5  // LED 3 : Scroll Lock
#define PIN_LED_DVORAK    6  // LED 4 : Mode Dvorak activé

// --- 2. ENCODEURS ROTATIFS (CLK, DT, SW) ---
// Encodeur 1 : Luminosité du rétroéclairage
#define ENC_LUM_CLK       7
#define ENC_LUM_DT        8
#define ENC_LUM_SW        9

// Encodeur 2 : Volume / Gain du microphone (Click = Mute Micro)
#define ENC_MIC_CLK       10
#define ENC_MIC_DT        11
#define ENC_MIC_SW        12

// Encodeur 3 : Volume sonore du système (Click = Mute Audio)
#define ENC_VOL_CLK       13
#define ENC_VOL_DT        14
#define ENC_VOL_SW        15

// --- 3. BUS I2C (MCP23017) ---
#define I2C_SDA           2   // GP2 — Bus données SDA
#define I2C_SCL           3   // GP3 — Bus horloge SCL @ 1 MHz
#define PIN_INT_KEYBOARD  1   // GP1 — Interruption wake-up matrice

// --- 4. ADRESSES MCP23017 ---
#define MCP_ADDR_ROWS     0x20  // MCP23017 #1 — Lignes (L0-L7, Port A OUT)
#define MCP_ADDR_COLS     0x21  // MCP23017 #2 — Colonnes (C0-C12, Port A+B IN)

// --- 5. DIMENSIONS MATRICE ---
const uint8_t NUM_ROWS = 8;
const uint8_t NUM_COLS = 13;

// --- 6. ÉTATS ET VARIABLES GLOBALES ---
bool modeDvorak          = false;  // Activation du layout Dvorak
bool brightnessMaxToggle = false;  // Bascule luminosité Min/Max
bool micMuted            = false;  // État Mute microphone
bool audioMuted          = false;  // État Mute audio

// Matrice d'état des touches (pour détection de changement d'état)
bool keyState[NUM_ROWS][NUM_COLS] = {false};

// Variables Anti-rebond (Debounce) pour les encodeurs
unsigned long lastDebounceTime = 0;
const unsigned long debounceDelay = 20; // ms

// Descripteur HID : Keyboard + Consumer Control
Adafruit_USBD_HID usbHid;
uint8_t const desc_hid_report[] = {
  TUD_HID_REPORT_DESC_KEYBOARD(HID_REPORT_ID(1)),
  TUD_HID_REPORT_DESC_CONSUMER(HID_REPORT_ID(2))
};

/* ============================================================================
 * PROTOTYPES DES FONCTIONS
 * ============================================================================ */
void initGPIO();
void setupMatrixHardware();
void updateLEDs();
void scanMatrixI2C();
void readEncoders();
void handleEncoderClick(uint8_t encoderId);
void processRowState(uint8_t row, uint16_t colsState);

/* ============================================================================
 * SETUP — Initialisation au démarrage
 * ============================================================================ */
void setup() {
  initGPIO();
  setupMatrixHardware();

  // Initialisation USB HID (TinyUSB Core RP2040)
  usbHid.setPollInterval(1); // Polling Rate 1000 Hz (1 ms)
  usbHid.setReportDescriptor(desc_hid_report, sizeof(desc_hid_report));
  usbHid.begin();

  // Attente de la connexion USB avec l'hôte
  while (!TinyUSBDevice.mounted()) {
    delay(10);
  }
}

/* ============================================================================
 * LOOP — Boucle principale (~1 ms par itération)
 * ============================================================================ */
void loop() {
  // Traitement interne USB TinyUSB (si requis par la plateforme)
  #if TinyUSB_Need_Task
    TinyUSBDevice.task();
  #endif

  // 1. Scan de la matrice de touches via I2C (MCP23017)
  scanMatrixI2C();

  // 2. Lecture des 3 encodeurs rotatifs et leurs boutons
  readEncoders();

  // 3. Mise à jour des 4 LEDs d'état
  updateLEDs();

  delay(1); // Délai de stabilisation de la boucle principale
}

/* ============================================================================
 * INITIALISATION DES GPIO DU RP2040-ZERO
 * ============================================================================ */
void initGPIO() {
  // Configuration des LEDs d'état (sorties numériques)
  pinMode(PIN_LED_NUM_FN, OUTPUT);  digitalWrite(PIN_LED_NUM_FN, LOW);
  pinMode(PIN_LED_CAPS,   OUTPUT);  digitalWrite(PIN_LED_CAPS,   LOW);
  pinMode(PIN_LED_SCROLL, OUTPUT);  digitalWrite(PIN_LED_SCROLL, LOW);
  pinMode(PIN_LED_DVORAK, OUTPUT);  digitalWrite(PIN_LED_DVORAK, LOW);

  // Configuration des encodeurs rotatifs (entrées avec pull-up interne)
  pinMode(ENC_LUM_CLK, INPUT_PULLUP);
  pinMode(ENC_LUM_DT,  INPUT_PULLUP);
  pinMode(ENC_LUM_SW,  INPUT_PULLUP);

  pinMode(ENC_MIC_CLK, INPUT_PULLUP);
  pinMode(ENC_MIC_DT,  INPUT_PULLUP);
  pinMode(ENC_MIC_SW,  INPUT_PULLUP);

  pinMode(ENC_VOL_CLK, INPUT_PULLUP);
  pinMode(ENC_VOL_DT,  INPUT_PULLUP);
  pinMode(ENC_VOL_SW,  INPUT_PULLUP);

  // Broche d'interruption pour le réveil depuis la veille
  pinMode(PIN_INT_KEYBOARD, INPUT_PULLUP);
  // attachInterrupt(PIN_INT_KEYBOARD, wakeFromSleep, FALLING); // À activer pour la veille
}

/* ============================================================================
 * CONFIGURATION HARDWARE DE LA MATRICE (MCP23017 via I2C)
 * Voir docs/05-analyse-gpio-extension.md pour le détail de l'architecture.
 * ============================================================================ */
void setupMatrixHardware() {
  Wire.setSCL(I2C_SCL);
  Wire.setSDA(I2C_SDA);
  Wire.begin();
  Wire.setClock(1000000); // I2C Fast-Mode Plus : 1 MHz

  // Configuration MCP23017 #1 (Lignes L0-L7) : Port A en SORTIE
  Wire.beginTransmission(MCP_ADDR_ROWS);
  Wire.write(0x00); // Registre IODIRA
  Wire.write(0x00); // 0x00 = Toutes les broches en sortie
  Wire.endTransmission();

  // Configuration MCP23017 #2 (Colonnes C0-C12) : Ports A et B en ENTRÉE
  Wire.beginTransmission(MCP_ADDR_COLS);
  Wire.write(0x00); // Registre IODIRA
  Wire.write(0xFF); // 0xFF = Toutes les broches Port A en entrée
  Wire.endTransmission();

  // Activation des résistances pull-up internes sur les colonnes (MCP23017 #2)
  Wire.beginTransmission(MCP_ADDR_COLS);
  Wire.write(0x0C); // Registre GPPUA (Pull-ups Port A)
  Wire.write(0xFF); // Pull-up activé sur Port A
  Wire.write(0xFF); // Pull-up activé sur Port B
  Wire.endTransmission();
}

/* ============================================================================
 * MISE À JOUR DES LEDs D'ÉTAT
 * Les LEDs 1-3 sont contrôlées par le rapport HID de l'hôte.
 * La LED 4 (Dvorak) est contrôlée directement par le firmware.
 * ============================================================================ */
void updateLEDs() {
  // LED 1: Num Lock / Mode Fn (signal reçu de l'hôte via USB HID)
  digitalWrite(PIN_LED_NUM_FN, (keyboard_led_state & KEYBOARD_LED_NUMLOCK)   ? HIGH : LOW);
  
  // LED 2: Caps Lock (signal reçu de l'hôte)
  digitalWrite(PIN_LED_CAPS,   (keyboard_led_state & KEYBOARD_LED_CAPSLOCK)  ? HIGH : LOW);
  
  // LED 3: Scroll Lock (signal reçu de l'hôte)
  digitalWrite(PIN_LED_SCROLL, (keyboard_led_state & KEYBOARD_LED_SCROLLLOCK)? HIGH : LOW);
  
  // LED 4: Mode Dvorak (variable interne firmware — indépendant de l'hôte)
  digitalWrite(PIN_LED_DVORAK, modeDvorak ? HIGH : LOW);
}

/* ============================================================================
 * BALAYAGE DE LA MATRICE VIA I2C (MCP23017)
 * Temps de scan estimé : ~300 µs à 1 MHz → invisible à la frappe (< 1 ms USB)
 * ============================================================================ */
void scanMatrixI2C() {
  for (uint8_t row = 0; row < NUM_ROWS; row++) {
    
    // Étape 1 : Activer UNE SEULE ligne (la mettre à LOW, toutes les autres HIGH)
    Wire.beginTransmission(MCP_ADDR_ROWS);
    Wire.write(0x12);           // Registre GPIOA
    Wire.write(~(1 << row));    // Seul le bit de la ligne courante est à 0
    Wire.endTransmission();

    // Étape 2 : Lire l'état des 13 colonnes sur MCP23017 #2
    // Port A = colonnes 0 à 7, Port B = colonnes 8 à 12
    Wire.beginTransmission(MCP_ADDR_COLS);
    Wire.write(0x12); // Registre GPIOA (lecture séquentielle A puis B)
    Wire.endTransmission();
    
    Wire.requestFrom(MCP_ADDR_COLS, 2); // 2 octets : Port A + Port B
    uint16_t colsState = Wire.read() | ((uint16_t)Wire.read() << 8);

    // Étape 3 : Traiter l'état des touches de cette ligne
    processRowState(row, colsState);
  }
}

/* ============================================================================
 * TRAITEMENT DE L'ÉTAT D'UNE LIGNE
 * Détecte les changements d'état et envoie les scancodes HID.
 * ============================================================================ */
void processRowState(uint8_t row, uint16_t colsState) {
  for (uint8_t col = 0; col < NUM_COLS; col++) {
    // Un bit à 0 signifie que la touche est pressée (pull-up + actif bas)
    bool pressed = !((colsState >> col) & 0x01);

    if (pressed != keyState[row][col]) {
      keyState[row][col] = pressed;
      
      if (pressed) {
        // Mapper la position (row, col) vers le HID Usage ID via la table active
        // uint8_t hidCode = activeKeymap[row * NUM_COLS + col];
        // Traiter les touches spéciales (Dvorak toggle, Fn, etc.)
        // Envoyer le rapport HID
      } else {
        // Retirer le HID Usage ID du rapport HID
      }
    }
  }
}

/* ============================================================================
 * LECTURE DES ENCODEURS ROTATIFS (Décodage en quadrature)
 * ============================================================================ */
void readEncoders() {
  static uint8_t lastLumCLK = HIGH;
  static uint8_t lastMicCLK = HIGH;
  static uint8_t lastVolCLK = HIGH;

  // ─── Encodeur 1 : Luminosité ───────────────────────────────────────────────
  uint8_t currentLumCLK = digitalRead(ENC_LUM_CLK);
  if (currentLumCLK != lastLumCLK && currentLumCLK == LOW) {
    if (digitalRead(ENC_LUM_DT) != currentLumCLK) {
      // Rotation horaire → Augmenter luminosité (PWM ou Consumer Code)
      // setBrightness(brightness + BRIGHTNESS_STEP);
    } else {
      // Rotation antihoraire → Diminuer luminosité
      // setBrightness(brightness - BRIGHTNESS_STEP);
    }
  }
  lastLumCLK = currentLumCLK;

  // Bouton encodeur luminosité — Bascule Min/Max
  if (digitalRead(ENC_LUM_SW) == LOW) {
    handleEncoderClick(1);
    delay(150); // Anti-rebond simplifié pour bouton
  }

  // ─── Encodeur 2 : Microphone ───────────────────────────────────────────────
  uint8_t currentMicCLK = digitalRead(ENC_MIC_CLK);
  if (currentMicCLK != lastMicCLK && currentMicCLK == LOW) {
    if (digitalRead(ENC_MIC_DT) != currentMicCLK) {
      // Rotation horaire → Gain Micro +
    } else {
      // Rotation antihoraire → Gain Micro -
    }
  }
  lastMicCLK = currentMicCLK;

  // Bouton encodeur microphone — Mute/Unmute Micro
  if (digitalRead(ENC_MIC_SW) == LOW) {
    handleEncoderClick(2);
    delay(150);
  }

  // ─── Encodeur 3 : Volume ───────────────────────────────────────────────────
  uint8_t currentVolCLK = digitalRead(ENC_VOL_CLK);
  if (currentVolCLK != lastVolCLK && currentVolCLK == LOW) {
    if (digitalRead(ENC_VOL_DT) != currentVolCLK) {
      // Consumer Control HID: Volume Increment (Usage 0x00E9)
    } else {
      // Consumer Control HID: Volume Decrement (Usage 0x00EA)
    }
  }
  lastVolCLK = currentVolCLK;

  // Bouton encodeur volume — Mute/Unmute Audio
  if (digitalRead(ENC_VOL_SW) == LOW) {
    handleEncoderClick(3);
    delay(150);
  }
}

/* ============================================================================
 * GESTION DES CLICS DES ENCODEURS
 * ============================================================================ */
void handleEncoderClick(uint8_t encoderId) {
  switch (encoderId) {
    case 1:
      // Click Luminosité : Bascule instantanée Min ↔ Max
      brightnessMaxToggle = !brightnessMaxToggle;
      // Appliquer le niveau max ou min au rétroéclairage (PWM)
      // analogWrite(PIN_BACKLIGHT, brightnessMaxToggle ? 255 : 0);
      break;

    case 2:
      // Click Microphone : Mute / Unmute Micro
      micMuted = !micMuted;
      // Envoyer HID Telephony Page - Mute (0x00CF)
      // usbHid.sendReport16(2, micMuted ? HID_USAGE_TELEPHONY_MUTE : 0);
      break;

    case 3:
      // Click Volume : Mute / Unmute Audio
      audioMuted = !audioMuted;
      // Envoyer HID Consumer Page - Mute (0x00E2)
      // usbHid.sendReport16(2, audioMuted ? HID_USAGE_CONSUMER_MUTE : 0);
      break;
  }
}
```

---

> **Page précédente :** [03 — Interface Homme-Machine (IHM)](./03-interface-ihm.md)  
> **Page suivante :** [05 — Analyse GPIO & Extension I2C](./05-analyse-gpio-extension.md)

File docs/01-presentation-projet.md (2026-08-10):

# 01 — Présentation du Projet Open-TPMX2030

> **Retour à l'index :** [Documentation](./README.md)

---

## Table des matières

- [01 — Présentation du Projet Open-TPMX2030](#01--présentation-du-projet-open-tpmx2030)
  - [Table des matières](#table-des-matières)
  - [Genèse du projet](#genèse-du-projet)
  - [Objectifs du projet](#objectifs-du-projet)
  - [Différences avec le TypeMatrix original](#différences-avec-le-typematrix-original)
  - [Organisation du dépôt Git](#organisation-du-dépôt-git)
    - [Structure des branches](#structure-des-branches)
    - [Structure des dossiers](#structure-des-dossiers)
    - [Bonnes pratiques de commit](#bonnes-pratiques-de-commit)
  - [Projets inspirants et références](#projets-inspirants-et-références)
    - [Projets communautaires](#projets-communautaires)
    - [Ressources](#ressources)

---

## Genèse du projet

Le projet **Open-TPMX2030** est né au sein du [FabLab Artilect](https://github.com/Artilect-FabTronic) de Toulouse, inspiré par la présentation du projet [**ToucheLibre**](https://touchelibre.fr/index.php/presentation-projet-en-video/) réalisée par **Lilian Tribouilloy** lors d'une soirée SuperLundi en mars 2020.

L'idée centrale : concevoir un **clavier mécanique open source**, fidèle à l'ergonomie orthogonale du [TypeMatrix 2030](https://typematrix.com/fr/products/2030/), mais en version entièrement DIY — avec des touches mécaniques Cherry MX2A, un microcontrôleur moderne et un firmware sur-mesure.

Le [TypeMatrix 2030](https://bepo.fr/wiki/TypeMatrix) est un clavier ergonomique réputé pour sa disposition en matrice orthogonale (colonnes verticales alignées), plébiscité par les utilisateurs des layouts alternatifs comme le **Bépo** (layout français ergonomique équivalent du Dvorak). La version USB commerciale existe, mais il n'existe pas de version mécanique officielle. Ce projet comble ce manque.

---

## Objectifs du projet

Le projet vise les objectifs suivants :

1. **Reproduire fidèlement la disposition physique orthogonale** du TypeMatrix 2030 en version mécanique.
2. **Intégrer des switches Cherry MX2A** interchangeables (via sockets hotswap si possible).
3. **Concevoir un PCB complet sous KiCad**, entièrement open source et reproductible en FabLab.
4. **Implémenter un firmware sur-mesure** (RP2040-Zero + Arduino-Pico) gérant nativement l'USB HID.
5. **Supporter plusieurs layouts** : QWERTY, Bépo, Dvorak, Colemak-DH — commutables directement depuis le clavier.
6. **Enrichir l'expérience utilisateur** avec 3 encodeurs rotatifs (luminosité, micro, volume) et 4 LEDs d'état.

---

## Différences avec le TypeMatrix original

| Critère | TypeMatrix 2030 USB | Open-TPMX2030 (ce projet) |
| --- | --- | --- |
| **Technologie des touches** | Membrane | Mécanique (Cherry MX2A) |
| **Microcontrôleur** | Propriétaire | RP2040-Zero (open source) |
| **Firmware** | Propriétaire | Arduino-Pico (open source) |
| **Encodeurs** | Absents | 3× EC11 (Luminosité, Micro, Volume) |
| **LEDs** | Basiques | 4× SMD 0805 (Num/Fn, Caps, Scroll, Dvorak) |
| **Conception PCB** | Fermée | KiCad open source |
| **Layouts firmware** | QWERTY + Dvorak | QWERTY, Bépo, Dvorak, Colemak-DH |
| **Source** | Commerciale | Open Source / FabLab |

---

## Organisation du dépôt Git

Le dépôt est hébergé sur GitHub :

📌 [https://github.com/Artilect-FabTronic/open-tpmx2030-keyboard](https://github.com/Artilect-FabTronic/open-tpmx2030-keyboard)

### Structure des branches

| Branche | Rôle |
| --- | --- |
| `main` | Branche principale **protégée** — aucun commit direct autorisé |
| `feature/pcb` | Fichiers KiCad et conception du PCB |
| `feature/firmware` | Code source du firmware |

> **Règle de contribution :** Toute contribution passe par une **Pull Request** depuis une branche feature vers `main`. Les commits directs sur `main` sont bloqués.

### Structure des dossiers

```plaintext
open-tpmx2030-keyboard/
├── README.md                  ← Point d'entrée du projet
├── docs/                      ← Documentation technique complète
│   ├── README.md              ← Index de navigation
│   ├── 01-presentation-projet.md
│   ├── 02-conception-hardware.md
│   ├── 03-interface-ihm.md
│   ├── 04-firmware-architecture.md
│   ├── 05-analyse-gpio-extension.md
│   ├── 06-dispositions-clavier.md
│   ├── 07-ressources-references.md
│   └── RP2040-Zero-Board/     ← Pinout et schéma du RP2040-Zero
├── images/                    ← Images du projet
├── pcb/                       ← Fichiers KiCad (branche feature/pcb)
└── .gitignore
```

### Bonnes pratiques de commit

Le projet suit la convention [Commitizen](https://commitizen-tools.github.io/commitizen/tutorials/writing_commits/) pour les messages de commit :

```
feat: add MX2A hotswap socket footprint in KiCad
fix: correct I2C pull-up resistor value on schematic
docs: update BOM with correct MCP23017 reference
chore: add .gitignore for KiCad temp files
```

---

## Projets inspirants et références

### Projets communautaires

| Projet | Description | Lien |
| --- | --- | --- |
| **ToucheLibre**  | Clavier open source de Lilian Tribouilloy (2020) | [gitlab.com/touchelibre](https://gitlab.com/touchelibre) |
| **ThinkMatrix**  | TypeMatrix mécanique DIY en bois avec Teensy | [forum.bepo.fr](https://forum.bepo.fr/d/1232-conception-clavier-typematrix-mechanique-version-2) |
| **Quacken** | Pro Micro RP2040 keyboard project | [github.com/Nuclear-Squid/Quacken](https://github.com/Nuclear-Squid/Quacken/tree/main/firmware)  |
| **DreymaR EPKL** | Big Bag Of Keyboard Tricks pour Colemak-DH | [github.com/DreymaR/BigBagKbdTrixPKL](https://github.com/DreymaR/BigBagKbdTrixPKL) |
| **keebee** | DIY USB Keyboard from Scratch (STM32) | [github.com/blakesmith/embedded](https://github.com/blakesmith/embedded/tree/master/keebee) |

### Ressources

- 📖 [Wiki Bépo — TypeMatrix](https://bepo.fr/wiki/TypeMatrix)
- 📹 [YouTube — I Built My DREAM Keyboard from SCRATCH](https://www.youtube.com/watch?v=KwFWBdfZKnI) ([Wiki](https://wiki.modhobbyist.com/Projects/0002%20-%20Split%20Keyboard%20-%20Mk.%201/1%20-%20Instructions.html))

---

> **Page suivante :** [02 — Conception Hardware & PCB](./02-conception-hardware.md)

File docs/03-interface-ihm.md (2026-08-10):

# 03 — Interface Homme-Machine (IHM)

> **Retour à l'index :** [Documentation](./README.md)

---

## Table des matières

- [Vue d'ensemble de l'IHM](#vue-densemble-de-lihm)
- [Encodeurs rotatifs EC11](#encodeurs-rotatifs-ec11)
- [LEDs d'état](#leds-détat)
- [Keycaps personnalisées](#keycaps-personnalisées)
- [Switches — Sockets Hotswap](#switches--sockets-hotswap)

---

## Vue d'ensemble de l'IHM

L'interface physique du clavier Open-TPMX2030 va au-delà de la simple frappe de touches. Elle intègre :

```plaintext
┌──────────────────────────────────────────────────────────────┐
│  [Enc 1: Luminosité]  [Enc 2: Micro]  [Enc 3: Volume]        │  ← Barre supérieure
│         [LED Num]  [LED Caps]  [LED Scroll]  [LED Dvorak]    │  ← Centre supérieur
├──────────────────────────────────────────────────────────────┤
│                                                              │
│         Matrice 8×13 — 102 touches Cherry MX2A               │  ← Zone de frappe
│         (Layout orthogonal — Type TypeMatrix)                │
│                                                              │
└──────────────────────────────────────────────────────────────┘
```

---

## Encodeurs rotatifs EC11

### Présentation

Les **encodeurs rotatifs EC11** sont des potentiomètres incrémentaux sans fin. Ils produisent deux signaux en quadrature (CLK et DT) permettant de détecter la direction et la vitesse de rotation. Chaque encodeur intègre également un **bouton poussoir** (switch) activé par pression axiale.

### Encodeur 1 — Luminosité du rétroéclairage

| Paramètre | Valeur |
| --- | --- |
| **Broches** | GP7 (CLK), GP8 (DT), GP9 (SW) |
| **Rotation horaire** | Augmente la luminosité |
| **Rotation antihoraire** | Diminue la luminosité |
| **Clic (pression)** | **Bascule instantané Min ↔ Max** |
| **Signal HID** | Consumer Control / PWM interne |

> Le clic de l'encodeur de luminosité permet de passer instantanément de l'éclairage minimal à maximal (ou inversement), pratique pour alterner rapidement entre environnements lumineux et sombres.

### Encodeur 2 — Gain du microphone

| Paramètre | Valeur |
| --- | --- |
| **Broches** | GP10 (CLK), GP11 (DT), GP12 (SW) |
| **Rotation horaire** | Augmente le gain micro |
| **Rotation antihoraire** | Diminue le gain micro |
| **Clic (pression)** | **Mute / Unmute microphone** |
| **Signal HID** | USB HID Telephony Page (Usage: Mute) |

> Fonction particulièrement utile en télétravail ou en visioconférence. Le clic coupe immédiatement le micro sans quitter l'application active.

### Encodeur 3 — Volume audio du système

| Paramètre | Valeur |
| --- | --- |
| **Broches** | GP13 (CLK), GP14 (DT), GP15 (SW) |
| **Rotation horaire** | Augmente le volume |
| **Rotation antihoraire** | Diminue le volume |
| **Clic (pression)** | **Mute / Unmute audio** |
| **Signal HID** | USB Consumer Control (Usage: Volume Up/Down/Mute) |

### Fonctionnement électrique — Décodage en quadrature

Les encodeurs EC11 produisent deux signaux décalés de 90° en phase :

```plaintext
Rotation horaire (+) :
  CLK : ‾‾|__|‾‾|__|‾‾
  DT  : _|‾‾|__|‾‾|__|‾

Rotation antihoraire (-) :
  CLK : ‾‾|__|‾‾|__|‾‾
  DT  : ‾|__|‾‾|__|‾‾|
```

Le firmware compare le front descendant de CLK avec l'état de DT pour déterminer la direction :

- `DT != CLK` au moment du front → **Rotation +**
- `DT == CLK` au moment du front → **Rotation −**

### Paramétrage anti-rebond

Les encodeurs mécaniques peuvent générer des faux signaux lors des transitions. Une constante de debounce est appliquée :

```cpp
const unsigned long debounceDelay = 20; // ms
```

Pour les boutons poussoirs des encodeurs, un délai simplifié de **150 ms** est appliqué après chaque clic détecté.

---

## LEDs d'état

### Disposition physique

Les 4 LEDs sont placées **au centre supérieur** du clavier, dans cet ordre de gauche à droite :

```plaintext
[ Num/Fn ]  [ Caps Lock ]  [ Scroll Lock ]  [ Dvorak ]
```

### Détail de chaque LED

#### LED 1 — Num Lock / Mode Fn (Bleue)

| Paramètre | Valeur |
| --- | --- |
| **Broche** | GP0 |
| **Couleur** | Bleue (SMD 0805) |
| **Signal de contrôle** | `KEYBOARD_LED_NUMLOCK` (rapport HID hôte) |
| **État ON** | Pavé numérique verrouillé **OU** couche Fn active |
| **État OFF** | Mode alphanumérique standard |

> La LED bleue signale également l'activation de la couche Fn (touches de fonctions spéciales en bleu sur les keycaps).

#### LED 2 — Caps Lock

| Paramètre | Valeur |
| --- | --- |
| **Broche** | GP4 |
| **Couleur** | Blanc ou ambre (SMD 0805) |
| **Signal de contrôle** | `KEYBOARD_LED_CAPSLOCK` (rapport HID hôte) |
| **État ON** | Majuscule verrouillée |
| **État OFF** | Mode minuscule normal |

#### LED 3 — Scroll Lock

| Paramètre | Valeur |
| --- | --- |
| **Broche** | GP5 |
| **Couleur** | Vert ou blanc (SMD 0805) |
| **Signal de contrôle** | `KEYBOARD_LED_SCROLLLOCK` (rapport HID hôte) |
| **État ON** | Défilement verrouillé |
| **État OFF** | Défilement normal |

#### LED 4 — Mode Dvorak

| Paramètre | Valeur |
| --- | --- |
| **Broche** | GP6 |
| **Couleur** | Rouge ou ambre (SMD 0805) |
| **Signal de contrôle** | Variable interne `modeDvorak` (firmware) |
| **État ON** | Layout Dvorak activé au niveau firmware  |
| **État OFF** | Layout QWERTY ou Bépo standard |

> Contrairement aux 3 premières LEDs (contrôlées par l'hôte via le rapport HID), la LED Dvorak est gérée **entièrement par le firmware** — son état reflète une configuration interne du clavier, indépendante du système d'exploitation.

### Code de mise à jour des LEDs

```cpp
void updateLEDs() {
  // LED 1: Verrouillage Num / Fn (signal hôte via USB HID)
  digitalWrite(PIN_LED_NUM_FN, (keyboard_led_state & KEYBOARD_LED_NUMLOCK) ? HIGH : LOW);
  
  // LED 2: Caps Lock (signal hôte)
  digitalWrite(PIN_LED_CAPS, (keyboard_led_state & KEYBOARD_LED_CAPSLOCK) ? HIGH : LOW);
  
  // LED 3: Scroll Lock (signal hôte)
  digitalWrite(PIN_LED_SCROLL, (keyboard_led_state & KEYBOARD_LED_SCROLLLOCK) ? HIGH : LOW);
  
  // LED 4: Mode Dvorak (variable interne firmware)
  digitalWrite(PIN_LED_DVORAK, modeDvorak ? HIGH : LOW);
}
```

---

## Keycaps personnalisées

### Contraintes spécifiques au TypeMatrix

Le layout orthogonal du TypeMatrix impose des keycaps à **profil bas** ou **plat** pour éviter les interférences entre touches adjacentes dans la disposition en grille. Les profils recommandés sont :

| Profil | Description | Compatibilité |
| --- | --- | --- |
| **XDA** | Sphérique uniforme, très bas | ✅ Idéal |
| **DSA** | Sphérique, uniformément bas  | ✅ Très bon |
| **MDA** | Modèle intermédiaire | ✅ Compatible |
| **SA row 3** | Cylindrique haut | ❌ Déconseillé |
| **OEM** | Standard incurvé | ⚠️ Possible mais non idéal |

### Configurateur et fournisseurs

- 🎨 **Design sur-mesure :** [ThockFactory Configurator](https://thockfactory.com/fr/configurator) — permet de définir les légendes (Bépo, Dvorak, QWERTY, couche Fn) et le profil.
- 🏺 **Keycaps en céramique :** [Cerakey](https://www.cerakey.com/fr) — keycaps premium en céramique (haptique unique).
- 🌐 **Tai-Hao** : [shop.tai-hao.com](https://shop.tai-hao.com/) — Large sélection de profils.

### Légendes recommandées

Les keycaps devraient afficher :
- **Face principale :** Légende Bépo (ou QWERTY selon configuration)
- **Sous-légende (en bas)** : Légende Dvorak ou alternative
- **Légende latérale ou côté :** Couche Fn (touches de fonction en bleu)

### Impression 3D de keycaps

Pour des keycaps prototypes ou entièrement personnalisées :

- **Format de fichier :** STL (impression FDM/résine) ou STEP (export pour fraise CNC)
- **Technique recommandée :** **Résine stéréolithographique (SLA)** pour la précision du stem (tige d'ancrage Cherry MX ≈ 4mm)
- **Plateformes de modèles :** [Cults3D](https://cults3d.com), [MakerWorld (Bambu Lab)](https://makerworld.com)
- **Projet de référence :** [KLP Lame Keycaps](https://github.com/braindefender/KLP-Lame-Keycaps) — keycaps sphériques pour switches low profile

> 📹 Tutoriel — Impression résine de keycaps : [YouTube Shorts](https://www.youtube.com/shorts/zBXvIhGU1K0)

---

## Switches — Sockets Hotswap

### Objectif

Rendre les switches **interchangeables sans dessoudage** grâce à des sockets PCB enfichables. Cela permet de tester différents types de switches (Brown, Blue, Linear) sans modifier le PCB.

### Options de sockets

| Référence | Type | Compatibilité | Remarque |
| --- | --- | --- | --- |
| **[Kailh CPG151101S11](https://kbdfans.com/products/mechanical-keyboard-switches-kailh-pcb-socket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)** | SMD | Cherry MX | Standard de la communauté DIY |
| **[Mill-Max 0305](https://www.mill-max.com/products/pin-receptacle/receptacle-with-no-tail/0305)** | Traversant | Cherry MX | Plus robuste, cher |
| **[Mill-Max 7305](https://www.mill-max.com/products/pin-receptacle/receptacle-with-no-tail/7305)** | Traversant | Cherry MX | Version ultra-bas profil |

### Considérations PCB

- L'utilisation de sockets augmente légèrement l'épaisseur du PCB (prévoir une platine ou boîtier adapté).
- L'empreinte KiCad pour les sockets Kailh est disponible dans la bibliothèque [MX_Alps_Hybrid](https://github.com/ai03-2725/MX_Alps_Hybrid).

---

> **Page précédente :** [02 — Conception Hardware & PCB](./02-conception-hardware.md)  
> **Page suivante :** [04 — Architecture Firmware](./04-firmware-architecture.md)

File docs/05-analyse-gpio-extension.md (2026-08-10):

# 05 — Analyse GPIO & Extension I2C (MCP23017)

> **Retour à l'index :** [Documentation](./README.md)

---

## Table des matières

- [Problématique : Contrainte GPIO du RP2040-Zero](#problématique--contrainte-gpio-du-rp2040-zero)
- [Étude comparative des topologies hardware](#étude-comparative-des-topologies-hardware)
- [Analyse critique des idées reçues sur la latence](#analyse-critique-des-idées-reçues-sur-la-latence)
- [Choix technologique retenu](#choix-technologique-retenu)
- [Architecture hardware détaillée](#architecture-hardware-détaillée)
- [Configuration de la matrice (NKRO)](#configuration-de-la-matrice-nkro)
- [Configuration I2C et interruptions](#configuration-i2c-et-interruptions)
- [Code de balayage I2C optimisé](#code-de-balayage-i2c-optimisé)
- [Conclusion](#conclusion)

---

## Problématique : Contrainte GPIO du RP2040-Zero

Le RP2040-Zero n'expose que **20 broches GPIO** accessibles (GP0 à GP15, GP26 à GP29).

### Inventaire des GPIOs consommées

| Périphérique | Broches utilisées  | Nombre |
| --- | --- | --- |
| 4 LEDs d'état | GP0, GP4, GP5, GP6 | 4 |
| Encodeur 1 (CLK, DT, SW) | GP7, GP8, GP9 | 3 |
| Encodeur 2 (CLK, DT, SW) | GP10, GP11, GP12 | 3 |
| Encodeur 3 (CLK, DT, SW) | GP13, GP14, GP15 | 3 |
| **Sous-total consommé**  | | **13** |
| **Restant disponible** | | **7**  |

### Besoin pour la matrice de touches

Une matrice directe 8 lignes × 13 colonnes nécessite au minimum :

```
8 (Lignes OUT) + 13 (Colonnes IN) = 21 GPIO
```

> **Conclusion :** Il ne reste que 7 GPIO disponibles, mais la matrice en exige 21.  
> **L'utilisation directe des broches du RP2040 est physiquement impossible.**  
> Un composant d'extension de GPIO est indispensable.

---

## Étude comparative des topologies hardware

Deux familles de solutions ont été étudiées :

### Option A — MCP23017 (Extenseur I2C)

Le **MCP23017** de Microchip est un extenseur 16 bits d'I/O sur bus I2C. Il fournit 16 broches GPIO supplémentaires via seulement 2 fils (SDA + SCL).

- 📄 [Datasheet MCP23017](https://ww1.microchip.com/downloads/aemDocuments/documents/APID/ProductDocuments/DataSheets/MCP23017-MCP23S17-16-Bit-IO-Expander-with-Serial-Interface-DS20001952.pdf)
- 🌐 [Page produit Microchip](https://www.microchip.com/en-us/product/mcp23017)

**Caractéristiques clés :**
- Interface : I2C (jusqu'à 1.7 MHz en Fast-Mode Plus)
- 16 GPIO configurables individuellement (IN / OUT / Pull-up / Open-drain)
- **2 broches d'interruption** (`INTA` / `INTB`) pour la détection de changement d'état sans polling
- Tension : 2.7V à 5.5V (compatible 3.3V RP2040)
- Courant max par broche : 20 mA
- Boîtier : SSOP-28 ou DIP-28
- Adressage : 3 bits hardware (A0, A1, A2) → jusqu'à 8 MCP23017 sur le même bus

### Option B — Registres à décalage (SPI)

Les **registres à décalage 74HC165** (parallèle → série, lecture des colonnes) et **74HC595** (série → parallèle, pilotage des lignes) permettent une extension via SPI.

| Critère | MCP23017 (I2C) | 74HC165/595 (SPI) |
| --- | --- | --- |
| **GPIO RP2040 utilisées** | **3** (SDA, SCL, INT) | **4** (SCK, MOSI, MISO, LATCH) |
| **Vitesse bus** | Jusqu'à 1 MHz (Fast-Mode+) | 10–20 MHz |
| **Temps scan matrice** | ~250–400 µs à 1 MHz | **~5–10 µs** à 20 MHz |
| **Latence globale** | < 0.5 ms | < 0.01 ms |
| **Veille / Wake-up** | **Natif** (INTA/INTB) | Nécessite porte logique OR dédiée |
| **Complexité PCB** | Faible (1 IC SSOP-28) | Moyenne (2–3 ICs en cascade) |
| **Coût** | ~0.80 € pièce | ~0.30 € pièce |
| **Anti-ghosting** | Requis (diodes 1N4148) | Requis (diodes 1N4148) |

---

## Analyse critique des idées reçues sur la latence

### Idée reçue n°1 : « L'I2C est trop lent pour un clavier »

Cette affirmation est vraie pour l'I2C standard à 100 kHz, mais **fausse** pour le RP2040 configuré en Fast-Mode Plus :

| Mode I2C | Fréquence | Temps lecture 1 octet | Temps scan 8 lignes |
| --- | --- | --- | --- |
| Standard | 100 kHz | ~100 µs | ~3.2 ms ❌ |
| Fast Mode | 400 kHz | ~25 µs | ~800 µs ⚠️ |
| **Fast-Mode Plus** | **1 MHz** | **~10 µs** | **~300 µs ✅** |

Le taux de rafraîchissement USB haute performance est de **1000 Hz (1 ms)**. Un scan de 300 µs reste **largement en dessous du seuil de latence perceptible**.

> 💡 **Conclusion :** À 1 MHz, la latence I2C est invisible à la frappe. L'argument de la lenteur I2C ne s'applique qu'aux configurations sous-optimales.

### Idée reçue n°2 : « Le SPI est toujours supérieur »

Le SPI est effectivement plus rapide (~5–10 µs de scan contre ~300 µs pour l'I2C), mais cette différence de **290 µs** est imperceptible pour l'être humain (le seuil de perception est ~10 ms).

**En revanche, le SPI présente un inconvénient majeur :** la gestion de la veille du RP2040 nécessite l'ajout d'une porte logique OR externe pour agréger les signaux de réveil des colonnes. Cela augmente la complexité du PCB et le nombre de composants.

### Idée reçue n°3 : « La veille n'est pas nécessaire pour un clavier »

Pour un clavier USB alimenté, la consommation en veille peut malgré tout être réduite en utilisant le mode `Dormant` du RP2040. Le **MCP23017** intègre nativement les broches `INTA` et `INTB` qui déclenchent une interruption matérielle dès qu'une touche est pressée, réveillant instantanément le microcontrôleur sans aucun composant supplémentaire.

---

## Choix technologique retenu

### ✅ Solution retenue : Double MCP23017 sur Bus I2C à 1 MHz

| Paramètre | Valeur |
| --- | --- |
| **Composants** | 2× MCP23017-E/SS (SSOP-28) |
| **GPIO RP2040 consommées** | 3 (SDA, SCL, INT) |
| **Capacité totale** | 32 E/S (16 × 2) |
| **Utilisation** | 8 Lignes (OUT) + 13 Colonnes (IN) = 21 I/O utilisées, 11 en réserve |
| **Vitesse bus I2C** | 1 MHz (Fast-Mode Plus) |
| **Temps scan estimé** | ~300 µs |
| **Veille/réveil** | Natif via INTA du MCP23017 |

### Répartition des deux MCP23017

| MCP23017 | Adresse I2C | Port A | Port B | Rôle |
| --- | --- | --- | --- | --- |
| **#1** | 0x20 | L0–L7 (OUT) | — | Pilotage des **Lignes**  |
| **#2** | 0x21 | C0–C7 (IN Pull-up) | C8–C12 (IN Pull-up) | Lecture des **Colonnes** |

### Configuration des adresses I2C

Les broches A0, A1, A2 du MCP23017 définissent les 3 bits de l'adresse :

| MCP23017 | A2  | A1  | A0  | Adresse I2C |
| --- | --- | --- | --- | ---: |
| #1 | 0 | 0 | 0 | `0x20` |
| #2 | 0 | 0 | 1 | `0x21` |

---

## Architecture hardware détaillée

```
                       RP2040-ZERO
                   +-----------------+
                   | GP2 (SDA) ------+-----------> Bus I2C (SDA)
                   |                 |              Pull-up 2.2kΩ vers 3.3V
                   | GP3 (SCL) ------+-----------> Bus I2C (SCL)
                   |                 |              Pull-up 2.2kΩ vers 3.3V
                   | GP1 (INT) ------+<----------- INTA (interruption combinée)
                   +-----------------+
                            |
           +----------------+----------------+
           |  Bus I2C @ 1 MHz                |
           |                                 |
  +-----------------+               +-----------------+
  |   MCP23017 #1   |               |   MCP23017 #2   |
  |  Adresse: 0x20  |               |  Adresse: 0x21  |
  |  A0=0, A1=0, A2=0               |  A0=1, A1=0, A2=0
  +-----------------+               +-----------------+
  | GPA0  → Ligne 0 |               | GPA0 ← Colonne 0|
  | GPA1  → Ligne 1 |               | GPA1 ← Colonne 1|
  | GPA2  → Ligne 2 |               | GPA2 ← Colonne 2|
  | GPA3  → Ligne 3 |               | GPA3 ← Colonne 3|
  | GPA4  → Ligne 4 |               | GPA4 ← Colonne 4|
  | GPA5  → Ligne 5 |               | GPA5 ← Colonne 5|
  | GPA6  → Ligne 6 |               | GPA6 ← Colonne 6|
  | GPA7  → Ligne 7 |               | GPA7 ← Colonne 7|
  +-----------------+               | GPB0 ← Colonne 8|
           |                        | GPB1 ← Colonne 9|
           |                        | GPB2 ← Col. 10  |
           |                        | GPB3 ← Col. 11  |
           |                        | GPB4 ← Col. 12  |
           |                        +-----------------+
           |                                 |
           +------------ MATRICE ------------+
                    8 Lignes × 13 Colonnes
                    ~102 Switches Cherry MX2A
                    + 102 Diodes 1N4148 (SOD-123)
```

---

## Configuration de la matrice (NKRO)

### Dimensions

```
8 Lignes (Output) × 13 Colonnes (Input Pull-up) = 104 emplacements
```

### Anti-ghosting — Full N-Key Rollover

Le **N-Key Rollover (NKRO)** garantit la détection simultanée de toutes les touches pressées, sans ambiguïté. Il est implémenté grâce à une **diode par switch** :

```
Ligne (active LOW)
    │
   [SW] ──── [>|] ──── Colonne (Pull-up)
   Switch     1N4148
   Cherry MX  SOD-123
```

- **Anode** de la diode → connectée à la ligne
- **Cathode** de la diode → connectée à la colonne (avec le switch)

Sans diodes, l'appui simultané de plusieurs touches crée des courts-circuits entre colonnes, générant des touches fantômes (ghosting). Les diodes bloquent le courant inverse et isolent chaque switch.

---

## Configuration I2C et interruptions

### Résistances de pull-up I2C

Le bus I2C nécessite des résistances de pull-up sur SDA et SCL :

| Fréquence I2C | Résistance recommandée |
| --- | --- |
| 100 kHz | 4.7 kΩ |
| 400 kHz | 2.2 kΩ |
| **1 MHz** | **2.2 kΩ** (ou 1 kΩ) |

### Configuration de l'interruption (MCP23017)

La broche `INTA` du MCP23017 est configurée en mode **Active-Low / Open-Drain** avec mirroring (`INTB` miroir d'`INTA`) :

```cpp
// Configuration du registre IOCON (Control Register)
// Bit 6 (MIRROR) = 1 : INTA et INTB sont couplées (l'une ou l'autre déclenche l'INT)
// Bit 2 (ODR)    = 1 : Sortie Open-Drain (compatible avec la broche INPUT_PULLUP du RP2040)
// Bit 1 (INTPOL) = 0 : Interruption active LOW

Wire.beginTransmission(MCP_ADDR_ROWS);
Wire.write(0x0A); // Registre IOCON
Wire.write(0b01000100); // MIRROR=1, ODR=1, INTPOL=0
Wire.endTransmission();

// Activer les interruptions sur changement d'état sur toutes les colonnes (MCP2)
Wire.beginTransmission(MCP_ADDR_COLS);
Wire.write(0x04); // Registre GPINTENA (enable interrupt Port A)
Wire.write(0xFF); // Interruption activée sur toutes les colonnes Port A
Wire.endTransmission();
```

### Wake-up depuis le mode Dormant

```cpp
// Activer l'interruption sur la broche GP1 pour le réveil
attachInterrupt(PIN_INT_KEYBOARD, []() {
  // Routine de réveil minimale (ISR)
  // Le RP2040 sort du mode Dormant automatiquement sur front descendant de GP1
}, FALLING);

// Entrer en mode Dormant (ultra-basse consommation)
// rp2040.dormant(); // À activer dans le firmware final
```

---

## Code de balayage I2C optimisé

```cpp
#include <Wire.h>

#define MCP_ADDR_ROWS 0x20
#define MCP_ADDR_COLS 0x21

/* ─── Initialisation de la matrice ─────────────────────────────────────────── */
void setupMatrixHardware() {
  Wire.setSCL(3); // GP3
  Wire.setSDA(2); // GP2
  Wire.begin();
  Wire.setClock(1000000); // I2C Fast-Mode Plus : 1 MHz

  // MCP23017 #1 — Lignes : Port A en SORTIE (toutes HIGH = inactives)
  Wire.beginTransmission(MCP_ADDR_ROWS);
  Wire.write(0x00); // Registre IODIRA
  Wire.write(0x00); // 0x00 = toutes les broches en sortie
  Wire.endTransmission();

  // Mettre toutes les lignes à HIGH (inactif)
  Wire.beginTransmission(MCP_ADDR_ROWS);
  Wire.write(0x12); // Registre GPIOA
  Wire.write(0xFF); // Toutes lignes HIGH
  Wire.endTransmission();

  // MCP23017 #2 — Colonnes : Ports A et B en ENTRÉE avec Pull-up
  Wire.beginTransmission(MCP_ADDR_COLS);
  Wire.write(0x00); // Registre IODIRA
  Wire.write(0xFF); // Port A en entrée
  Wire.endTransmission();

  Wire.beginTransmission(MCP_ADDR_COLS);
  Wire.write(0x0C); // Registre GPPUA
  Wire.write(0xFF); // Pull-up Port A activé
  Wire.write(0xFF); // Pull-up Port B activé
  Wire.endTransmission();
}

/* ─── Balayage ultra-rapide : exécuté toutes les ~1 ms ─────────────────────── */
void scanMatrixI2C() {
  for (uint8_t row = 0; row < 8; row++) {
    
    // Activer une seule ligne (mettre à LOW, toutes les autres HIGH)
    Wire.beginTransmission(MCP_ADDR_ROWS);
    Wire.write(0x12);         // Registre GPIOA
    Wire.write(~(1 << row));  // Bit row à 0, tous les autres à 1
    Wire.endTransmission();

    // Lire l'état des 13 colonnes (Port A + Port B de MCP23017 #2)
    Wire.beginTransmission(MCP_ADDR_COLS);
    Wire.write(0x12); // Registre GPIOA (lecture séquentielle A→B)
    Wire.endTransmission();
    
    Wire.requestFrom(MCP_ADDR_COLS, 2); // 2 octets : Port A + Port B
    uint16_t colsState = Wire.read() | ((uint16_t)Wire.read() << 8);

    // Traitement anti-rebond et gestion des touches de la ligne
    processRowState(row, colsState);
  }
}
```

### Calcul du temps de scan

Avec l'I2C à 1 MHz (Fast-Mode Plus) :

| Opération | Nombre | Temps estimé |
| --- | --- | --- |
| Écriture ligne active (1 octet) | 8 × | 8 × ~10 µs = **80 µs**  |
| Lecture 2 octets colonnes | 8 × | 8 × ~20 µs = **160 µs** |
| Overhead I2C (start/stop/ack) | ~16 ×  | ~60 µs |
| **Total estimé** | | **~300 µs** |

> **300 µs << 1000 µs (période USB @ 1000 Hz)** → Aucune latence perceptible.

---

## Conclusion

La topologie basée sur **2× MCP23017 cadencés à 1 MHz** offre le meilleur compromis pour ce projet :

| Critère | Résultat |
| --- | --- |
| **GPIO libérées**  | 17 GPIO sur 20 disponibles pour LEDs, encodeurs, extensions |
| **Temps de scan**  | ~300 µs (invisible à la frappe) |
| **Gestion veille** | Natif via INTA/INTB sans composant additionnel |
| **Complexité PCB** | Minimale (2 × SSOP-28, résistances pull-up, découplage) |
| **NKRO** | Garanti par les diodes 1N4148 sur chaque switch |
| **Évolutivité** | 11 GPIO MCP en réserve pour rétroéclairage, extensions futures |

---

> **Page précédente :** [04 — Architecture Firmware](./04-firmware-architecture.md)  
> **Page suivante :** [06 — Dispositions Clavier](./06-dispositions-clavier.md)

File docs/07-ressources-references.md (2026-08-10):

# 07 — Ressources & Références

> **Retour à l'index :** [Documentation](./README.md)

---

## Table des matières

- [Datasheets et documentation technique](#datasheets-et-documentation-technique)
- [Dépôts GitHub et bibliothèques](#dépôts-github-et-bibliothèques)
- [Tutoriels vidéo](#tutoriels-vidéo)
- [Fournisseurs de composants](#fournisseurs-de-composants)
- [Fournisseurs de keycaps](#fournisseurs-de-keycaps)
- [Projets DIY inspirants](#projets-diy-inspirants)
- [Communautés et forums](#communautés-et-forums)
- [Ressources institutionnelles](#ressources-institutionnelles)

---

## Datasheets et documentation technique

### Microcontrôleur RP2040

| Document | Description | Lien |
| --- | --- | --- |
| **RP2040 Datasheet** | Référence complète du chip (mémoire, PIO, USB, GPIO...) | [raspberrypi.com](https://pip-assets.raspberrypi.com/categories/814-rp2040/documents/RP-008371-DS-1-rp2040-datasheet.pdf) |
| **Hardware Design with RP2040** | Guide de conception hardware (découplage, USB, flash) | [raspberrypi.com](https://pip-assets.raspberrypi.com/categories/814-rp2040/documents/RP-008279-DS-1-hardware-design-with-rp2040.pdf) |
| **Waveshare RP2040-Zero Wiki**  | Documentation officielle de la carte Waveshare | [waveshare.com](https://www.waveshare.com/wiki/RP2040-Zero) |
| **TinyGo RP2040-Zero Pinout** | Référence des constantes de broches | [tinygo.org](https://tinygo.org/docs/reference/microcontrollers/machine/waveshare-rp2040-zero/) |
| **Arduino-Pico Guide** | Guide d'utilisation Arduino pour le RP2040 (Adafruit) | [adafruit.com](https://cdn-learn.adafruit.com/downloads/pdf/rp2040-arduino-with-the-earlephilhower-core.pdf) |

### Extenseur GPIO MCP23017

| Document | Description | Lien |
| --- | --- | --- |
| **MCP23017 Datasheet** | Datasheet complète (registres, I2C, interruptions) | [microchip.com](https://ww1.microchip.com/downloads/aemDocuments/documents/APID/ProductDocuments/DataSheets/MCP23017-MCP23S17-16-Bit-IO-Expander-with-Serial-Interface-DS20001952.pdf) |
| **Page produit MCP23017** | Outils de sélection et alternatives | [microchip.com](https://www.microchip.com/en-us/product/mcp23017) |

### Protocole USB HID

| Document | Description | Lien |
| --- | --- | --- |
| **Arduino USB HID Reference** | Référence de la bibliothèque clavier Arduino | [docs.arduino.cc](https://docs.arduino.cc/language-reference/en/functions/usb/Keyboard/) |
| **Keyboard Modifiers & Special Keys** | Codes des modificateurs et touches spéciales | [docs.arduino.cc](https://docs.arduino.cc/language-reference/en/functions/usb/Keyboard/keyboardModifiers/) |
| **Docs numériques — Claviers** | Documentation française sur les claviers et HID | [numerique.gouv.fr](https://docs.numerique.gouv.fr/docs/51d17aac-0f69-47e5-ac53-45f855d158d7/) |

---

## Dépôts GitHub et bibliothèques

### Firmware et bibliothèques Arduino-Pico

| Dépôt | Description |
| --- | --- |
| [earlephilhower/arduino-pico](https://github.com/earlephilhower/arduino-pico) | Core Arduino non-officiel pour RP2040 — bibliothèques, exemples |
| [arduino-pico/libraries/Keyboard](https://github.com/earlephilhower/arduino-pico/tree/master/libraries/Keyboard) | Bibliothèque Keyboard pour RP2040 |
| [KeyboardPassword.ino](https://github.com/earlephilhower/arduino-pico/blob/master/libraries/Keyboard/examples/KeyboardPassword/KeyboardPassword.ino) | Exemple d'utilisation de la bibliothèque Keyboard |
| [earlephilhower/Keyboard](https://github.com/earlephilhower/Keyboard) | Bibliothèque Keyboard standalone |

### Projets de claviers DIY de référence

| Dépôt | Description |
| --- | --- |
| [blakesmith/embedded/keebee](https://github.com/blakesmith/embedded/tree/master/keebee) | DIY USB Keyboard from Scratch (STM32F042K6T6) — référence complète |
| [Nuclear-Squid/Quacken](https://github.com/Nuclear-Squid/Quacken/tree/main/firmware) | Firmware clavier Pro Micro RP2040 |
| [MakerIO-Hub — Macro Pad ESP32-S3](https://github.com/MakerIO-Hub/I-Built-My-Own-Macro-Pad-From-Scratch-with-ESP32-S3) | Macro pad DIY ESP32-S3 avec KiCad |
| [esp32beans/ESP32_USB_Host_HID](https://github.com/esp32beans/ESP32_USB_Host_HID) | USB Host HID sur ESP32 |

### Layouts et ergonomie

| Dépôt | Description |
| --- | --- |
| [DreymaR/BigBagKbdTrixPKL](https://github.com/DreymaR/BigBagKbdTrixPKL) | Big Bag of Keyboard Tricks — Colemak-DH, EPKL |
| [EPKL_Layouts_Default.ini](https://github.com/DreymaR/BigBagKbdTrixPKL/blob/main/EPKL_Layouts_Default.ini) | Fichier de configuration EPKL |
| [Delapouite/awesome-keyboard](https://github.com/Delapouite/awesome-keyboard) | Liste curated de ressources claviers |
| [braindefender/KLP-Lame-Keycaps](https://github.com/braindefender/KLP-Lame-Keycaps) | Keycaps sphériques imprimées 3D |
| [keebio/cepstrum-case](https://github.com/keebio/cepstrum-case) | Boîtier clavier imprimé 3D |
| [touchelibre (GitLab)](https://gitlab.com/touchelibre) | Projet ToucheLibre de Lilian Tribouilloy |

### Dépôt de ce projet

| Dépôt | Description |
| --- | --- |
| [Artilect-FabTronic/open-tpmx2030-keyboard](https://github.com/Artilect-FabTronic/open-tpmx2030-keyboard) | Dépôt principal du projet |

---

## Tutoriels vidéo

### Microcontrôleur RP2040

| Titre | Chaîne | Lien |
| --- | --- | --- |
| **EB_#698 Flash — Le RP2040-Zero, Le Petit Raspberry Pi Pico!** | Électro-Bidouilleur | [YouTube](https://www.youtube.com/watch?v=h4QJl2mEFyY) |
| **Getting Started with Waveshare RP2040-Zero \| Blink LED** | — | [YouTube](https://www.youtube.com/watch?v=Vx-Y7pCRSJY) |

### Claviers DIY et HID

| Titre | Chaîne | Lien |
| --- | --- | --- |
| **Making My Own USB Keyboard From Scratch (STM32F042)** | Blake Smith | [Article + code](https://blakesmith.me/2019/01/16/making-my-own-usb-keyboard-from-scratch.html) |
| **J'ai construit mon propre macro pad ESP32-S3 (de A à Z)** | MakerIO | [YouTube](https://www.youtube.com/watch?v=Mk3VkKXWFn4) |
| **I'm Building My Own Macro Keyboard — ESP32-S3, KiCad, PCB #1** | MakerIO | [YouTube](https://www.youtube.com/watch?v=A0w_XrWLfuM) |
| **USB Keyboard and Mouse on ESP32-S2/S3** | — | [YouTube](https://www.youtube.com/watch?v=tdTQtg8-1n4) |
| **DIY HID USB Keyboard Using STM32 [HAL]** | Instructables | [instructables.com](https://www.instructables.com/STM32-As-HID-USB-Keyboard-STM32-Tutorials/) |

### Design claviers ergonomiques

| Titre | Chaîne | Lien |
| --- | --- | --- |
| **CMKB SoflePLUS2 Review — Neat New Ideas** | — | [YouTube](https://www.youtube.com/watch?v=phtbv2l8srY) |
| **How (Not) To Build An Open Source Keyboard feat. TOTEM** | — | [YouTube](https://www.youtube.com/watch?v=aVhC3ekbFAs) |
| **Creator Micro 2 body swap (Work Louder)** | Work Louder | [YouTube](https://www.youtube.com/watch?v=E-NVRhMK8tg) |

### Impression 3D de keycaps

| Titre | Lien |
| --- | --- |
| **Impression de touche de clavier avec de la résine** | [YouTube Shorts](https://www.youtube.com/shorts/zBXvIhGU1K0) |

---

## Fournisseurs de composants

### Switches mécaniques

| Fournisseur | Produit | Lien |
| --- | --- | --- |
| **Cherry** | MX2A Brown (V1 — Tactile) | [cherry.de](https://www.cherry.de/en-gb/product/mx2a-brown) |
| **Cherry** | MX2A Blue (V2 — Clicky) | [cherry.de](https://www.cherry.de/en-gb/product/mx2a-blue) |
| **RS-Online** | Interrupteurs de clavier | [rs-online.com](https://fr.rs-online.com/web/p/interrupteurs-de-clavier/0664569) |
| **Mouser** | Cherry Electrical (catalogue) | [mouser.fr](https://www.mouser.fr/fr/manufacturer/cherry-electrical/) |
| **Gateron** | Switches alternatifs | [gateron.co](https://www.gateron.co/) |

### Microcontrôleurs et modules

| Fournisseur | Produit | Lien |
| --- | --- | --- |
| **Amazon FR**  | RP2040-Zero lot de 6 | [amazon.fr](https://www.amazon.fr/dp/B0H3ZWW6R3/ref=sspa_dk_detail_5) |
| **OpenElab** | RP2040-Zero | [openelab.io](https://openelab.io/fr/products/rp2040-zero-a-pico) |
| **Gotronic** | Raspberry Pi Pico SC0915 | [gotronic.fr](https://www.gotronic.fr/art-carte-raspberry-pi-pico-33027.htm) |
| **AliExpress** | ESP32-C3 SuperMini (alternatif) | [aliexpress.com](https://fr.aliexpress.com/item/1005012143614522.html) |

---

## Fournisseurs de keycaps

| Fournisseur | Spécialité | Lien |
| --- | --- | --- |
| **ThockFactory** | Configurateur keycaps sur-mesure (légendes Bépo/Dvorak) | [thockfactory.com](https://thockfactory.com/fr/configurator) |
| **Cerakey** | Keycaps en céramique premium | [cerakey.com](https://www.cerakey.com/fr) |
| **Tai-Hao** | Large sélection profils et couleurs | [shop.tai-hao.com](https://shop.tai-hao.com/) |
| **Keeb.io** | Boutique DIY keyboards | [keeb.io](https://keeb.io/collections/keyboards) |

---

## Projets DIY inspirants

### ToucheLibre (2020) — Lilian Tribouilloy

Projet fondateur ayant inspiré l'Open-TPMX2030, présenté au FabLab Artilect lors d'une soirée SuperLundi en mars 2020.

- 🌐 [Site ToucheLibre](https://touchelibre.fr/index.php/presentation-projet-en-video/)
- 📦 [GitLab ToucheLibre](https://gitlab.com/touchelibre)

### ThinkMatrix — TypeMatrix mécanique DIY

Réalisation communautaire d'un TypeMatrix mécanique en bois avec un microcontrôleur Teensy, discutée sur le forum Bépo.

- 🌐 [Fil de discussion forum Bépo](https://forum.bepo.fr/d/1232-conception-clavier-typematrix-mechanique-version-2)

### keebee — DIY USB Keyboard from Scratch (Blake Smith)

Projet de référence pour la conception d'un clavier USB HID complet depuis zéro, avec STM32F042K6T6.

- 📝 [Article de blog](https://blakesmith.me/2019/01/16/making-my-own-usb-keyboard-from-scratch.html)
- 📦 [Code source GitHub](https://github.com/blakesmith/embedded/tree/master/keebee)

> La boucle firmware décrite par Blake Smith correspond exactement à l'approche retenue pour le Open-TPMX2030 :
>
> 1. Scanner toutes les touches de la matrice.
> 2. Associer les positions aux symboles (selon le layout actif).
> 3. Générer des paquets USB HID et les envoyer.
> 4. Mettre à jour les LEDs selon l'état des touches.

### Dreymar's Big Bag of Keyboard Tricks

Référence incontournable pour les layouts alternatifs avancés (Colemak-DH, Angle Mod, Wide Mod, etc.) sur Windows (EPKL) et Linux (XKB).

- 🌐 [dreymar.colemak.org](https://dreymar.colemak.org/)
- 📦 [GitHub EPKL](https://github.com/DreymaR/BigBagKbdTrixPKL)

---

## Communautés et forums

| Communauté | Description | Lien |
| --- | --- | --- |
| **Forum Bépo** | Référence francophone layouts ergonomiques | [forum.bepo.fr](https://forum.bepo.fr) |
| **r/MechanicalKeyboards** | Grande communauté internationale claviers mécaniques | [reddit.com](https://reddit.com/r/MechanicalKeyboards) |
| **Locoduino** | Communauté francophone Arduino/RP2040 | [locoduino.org](https://www.locoduino.org/spip.php?article319) |
| **Framboise 314** | Blog français Raspberry Pi / RP2040 | [framboise314.fr](https://www.framboise314.fr/carte-waveshare-rp2040-zero/) |
| **Linagora** | Communauté open source française | [inagora.fr](https://inagora.fr/) |

---

## Ressources institutionnelles

| Ressource | Description | Lien |
| --- | --- | --- |
| **Raspberry Pi — Pico Series** | Documentation officielle Pico / RP2040 | [raspberrypi.com](https://www.raspberrypi.com/documentation/microcontrollers/pico-series.html) |
| **Raspberry Pi Pico — Wikipedia FR**  | Article Wikipédia en français | [wikipedia.org](https://fr.wikipedia.org/wiki/Raspberry_Pi_Pico) |
| **Disposition Dvorak — Wikipedia FR** | Article Wikipédia sur le Dvorak | [wikipedia.org](https://fr.wikipedia.org/wiki/Disposition_Dvorak) |
| **Commitizen** | Guide des bonnes pratiques de commit | [commitizen-tools.github.io](https://commitizen-tools.github.io/commitizen/tutorials/writing_commits/) |

---

> **Page précédente :** [06 — Dispositions Clavier](./06-dispositions-clavier.md)  
> **Retour à l'index :** [Documentation](./README.md)

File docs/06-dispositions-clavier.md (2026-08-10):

# 06 — Dispositions Clavier

> **Retour à l'index :** [Documentation](./README.md)

---

## Table des matières

- [06 — Dispositions Clavier](#06--dispositions-clavier)
  - [Table des matières](#table-des-matières)
  - [Vue d'ensemble des layouts supportés](#vue-densemble-des-layouts-supportés)
  - [Layout QWERTY](#layout-qwerty)
  - [Layout Bépo](#layout-bépo)
    - [Principes ergonomiques du Bépo](#principes-ergonomiques-du-bépo)
    - [Image de référence — TypeMatrix 2030 Bépo](#image-de-référence--typematrix-2030-bépo)
    - [Ressources](#ressources)
  - [Layout Dvorak](#layout-dvorak)
    - [Rangée de repos Dvorak](#rangée-de-repos-dvorak)
    - [Comparaison QWERTY vs Dvorak vs Bépo](#comparaison-qwerty-vs-dvorak-vs-bépo)
  - [Layout Colemak-DH](#layout-colemak-dh)
    - [Ressources Colemak-DH](#ressources-colemak-dh)
  - [Outils logiciels par système d'exploitation](#outils-logiciels-par-système-dexploitation)
    - [Sous Windows](#sous-windows)
    - [Sous macOS](#sous-macos)
    - [Sous Linux](#sous-linux)
    - [Multiplateforme / Web](#multiplateforme--web)
  - [Outils de conception du layout physique](#outils-de-conception-du-layout-physique)
    - [Keyboard Layout Editor (KLE)](#keyboard-layout-editor-kle)
    - [Ergogen](#ergogen)
    - [Tableau récapitulatif — Outils et usages](#tableau-récapitulatif--outils-et-usages)
  - [Ressources communautaires](#ressources-communautaires)

---

## Vue d'ensemble des layouts supportés

L'Open-TPMX2030 supporte nativement **4 layouts** commutables directement depuis le firmware, sans modifier la configuration de l'OS :

```
┌─────────────┐   ┌─────────────┐   ┌─────────────┐   ┌─────────────┐
│   QWERTY    │   │    Bépo     │   │   Dvorak    │   │ Colemak-DH  │
│  (Standard) │   │ (Français)  │   │  (Anglais)  │   │  (Moderne)  │
│    LED OFF  │   │   LED OFF   │   │  LED Dvorak │   │   LED OFF   │
└─────────────┘   └─────────────┘   └─────────────┘   └─────────────┘
```

La LED **Dvorak** (GP6) s'allume uniquement en mode Dvorak. Les autres layouts ne modifient pas les LEDs d'état (la commutation est visible uniquement via le comportement des touches).

> Pour la commutation entre layouts, voir : [04 — Architecture Firmware](./04-firmware-architecture.md#gestion-des-layouts-alternatifs)

---

## Layout QWERTY

Le **QWERTY** est le layout standard international, utilisé par défaut sur la quasi-totalité des claviers commerciaux. Il sert de référence de compatibilité universelle.

| Caractéristique | Valeur |
| --- | --- |
| **Usage** | Standard international |
| **Idéal pour** | Compatibilité maximale, logiciels avec raccourcis QWERTY |
| **LED indicatrice** | Aucune (état par défaut) |

**Disposition de référence du TypeMatrix QWERTY :**

```
[ Esc][ 1 ][ 2 ][ 3 ][ 4 ][ 5 ][Bksp][ 6 ][ 7 ][ 8 ][ 9 ][ 0 ][ - ]
[ Tab][ Q ][ W ][ E ][ R ][ T ][Del ][ Y ][ U ][ I ][ O ][ P ][ \ ]
[Caps][ A ][ S ][ D ][ F ][ G ][↵   ][ H ][ J ][ K ][ L ][ ; ][ ' ]
[Shft][ Z ][ X ][ C ][ V ][ B ][     ][ N ][ M ][ , ][ . ][ / ][Shft]
```

---

## Layout Bépo

Le **Bépo** est une disposition de clavier française ergonomique, conçue pour optimiser la frappe en langue française. C'est l'équivalent francophone du Dvorak.

| Caractéristique | Valeur |
| --- | --- |
| **Usage** | Frappe en français, ergonomie |
| **Créateur** | Projet communautaire (2008) |
| **Idéal pour** | Rédaction française intensive |
| **LED indicatrice** | Aucune (si configuré par défaut) |
| **Référence** | [bepo.fr](https://bepo.fr) |

### Principes ergonomiques du Bépo

- Les **lettres les plus fréquentes** du français (e, s, a, r, t, n, i, u) sont placées sur la **rangée de repos** (home row).
- Les touches **rares** sont repoussées vers les bords.
- Les caractères accentués (é, è, à, ù, ç) sont directement accessibles.

### Image de référence — TypeMatrix 2030 Bépo

TypeMatrix 2030 Bépo layout

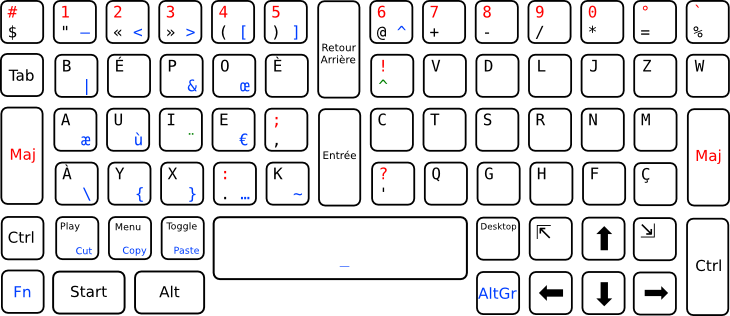
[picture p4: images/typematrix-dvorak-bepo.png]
Comparaison Dvorak / Bépo


### Ressources

- 📖 [Wiki Bépo — TypeMatrix](https://bepo.fr/wiki/TypeMatrix)
- 📖 [Documentation numérique.gouv.fr — Bépo](https://docs.numerique.gouv.fr/docs/51d17aac-0f69-47e5-ac53-45f855d158d7/)
- 🌐 [Forum Bépo — Projet TypeMatrix Mécanique](https://forum.bepo.fr/d/1232-conception-clavier-typematrix-mechanique-version-2)

---

## Layout Dvorak

La **disposition Dvorak** (inventée par August Dvorak en 1936) redistribue les touches pour placer les lettres les plus fréquentes (en anglais) sur la rangée de repos.

| Caractéristique | Valeur |
| --- | --- |
| **Usage** | Frappe en anglais, ergonomie |
| **LED indicatrice** | **LED 4 (Dvorak) allumée** |
| **Référence** | [Wikipedia — Dvorak](https://fr.wikipedia.org/wiki/Disposition_Dvorak) |

### Rangée de repos Dvorak

```
QWERTY  :  A  S  D  F  G  H  J  K  L  ;  '
Dvorak  :  A  O  E  U  I  D  H  T  N  S  -
```

### Comparaison QWERTY vs Dvorak vs Bépo

| Critère | QWERTY | Dvorak  | Bépo |
| --- | --- | --- | --- |
| **Langue optimisée** | — (historique) | Anglais | Français |
| **Déplacement des doigts** | Élevé | Réduit  | Réduit |
| **Apprentissage** | Standard | ~100h | ~100h |
| **Accessibilité accents FR** | ⚠️ AltGr requis | ⚠️ | ✅ Direct |

---

## Layout Colemak-DH

Le **Colemak-DH** (variante DH = "Mod-DH" de Colemak) est un layout moderne optimisé pour minimiser les mouvements latéraux des index. Il représente une évolution du Colemak original, réduisant le recours aux touches centrales peu ergonomiques (touches B, Y en QWERTY).

| Caractéristique | Valeur |
| --- | --- |
| **Usage** | Frappe anglaise/multilingue à haute performance |
| **LED indicatrice** | Aucune |
| **Référence** | [DreymaR EPKL](https://github.com/DreymaR/BigBagKbdTrixPKL) |
| **Compatibilité firmware** | Via les fichiers EPKL |

### Ressources Colemak-DH

- 🌐 [Site DreymaR — Colemak Big Bag](https://dreymar.colemak.org/)
- 📦 [GitHub — BigBagKbdTrixPKL](https://github.com/DreymaR/BigBagKbdTrixPKL)
- 📄 [Fichier de configuration EPKL](https://github.com/DreymaR/BigBagKbdTrixPKL/blob/main/EPKL_Layouts_Default.ini)

---

## Outils logiciels par système d'exploitation

Ces outils permettent de modifier la disposition logique des touches **au niveau de l'OS**, indépendamment du firmware du clavier. Utiles pour tester un layout avant de l'intégrer dans le firmware.

### Sous Windows

| Outil | Description | Lien |
| --- | --- | --- |
| **Microsoft MSKLC** | Outil officiel pour créer/modifier des layouts (.KLC) — définit chaque touche, Shift, AltGr | [microsoft.com](https://www.microsoft.com/en-us/download/details.aspx?id=102134) |
| **AutoHotkey** | Scripts pour remapper des touches ou créer des macros — idéal pour tester rapidement | [autohotkey.com](https://www.autohotkey.com/) |
| **WinCompose** | Ajoute une touche "Compose" pour les caractères spéciaux | [github.com/samhocevar/wincompose](https://github.com/samhocevar/wincompose) |
| **EPKL (DreymaR)**  | Implémentation Windows de Colemak-DH et variantes | [github.com/DreymaR/BigBagKbdTrixPKL](https://github.com/DreymaR/BigBagKbdTrixPKL) |

### Sous macOS

| Outil | Description | Lien |
| --- | --- | --- |
| **Karabiner-Elements** | Remapping de touches, couches personnalisées, comportement en temps réel | [karabiner-elements.pqrs.org](https://karabiner-elements.pqrs.org/) |

### Sous Linux

| Outil | Description | Lien |
| --- | --- | --- |
| **XKB** | Système natif de configuration clavier (X Window). Technique mais très flexible | [Arch Linux Wiki XKB](https://wiki.archlinux.org/title/X_keyboard_extension) |
| **Kalamine** | Outil moderne et convivial pour créer des layouts multiplateforme (Windows, macOS, Linux) — utilisé pour Ergo-L | [github.com/nicowillis/kalamine](https://github.com/nicowillis/kalamine) |
| **xcape** | Permet à une touche modificatrice seule d'émettre un caractère différent | — |
| **xdotool**  | Simulation d'appuis clavier/souris — utile pour les tests | — |
| **xev** | Affiche les événements X11 d'un clavier — utile pour déboguer | — |

### Multiplateforme / Web

| Outil | Description | Lien |
| --- | --- | --- |
| **Keyman Developer** | Création de layouts pour Windows, macOS, Linux, iOS, Android, Web | [keyman.com](https://keyman.com/developer/) |

---

## Outils de conception du layout physique

Ces outils permettent de **concevoir visuellement la disposition physique** des touches avant de créer le PCB.

### Keyboard Layout Editor (KLE)

[**Keyboard Layout Editor**](http://www.keyboard-layout-editor.com/) est l'outil en ligne de référence pour dessiner la disposition physique des touches :

- Visualisation en temps réel
- Choix des tailles, formes, couleurs
- Export JSON pour Ergogen/KiCad

### Ergogen

[**Ergogen**](https://ergogen.xyz/new) est un générateur de PCB ergonomique basé sur un fichier de configuration YAML. Il est particulièrement adapté aux claviers ortholinéaires comme le TypeMatrix.

```yaml
# Exemple de configuration Ergogen (extrait)
points:
  zones:
    matrix:
      columns:
        outer: { key: { col_net: C0 } }
        pinky: { key: { col_net: C1 } }
        ring:  { key: { col_net: C2 } }
        # ...
      rows:
        bottom: { row_net: R0 }
        home:   { row_net: R1 }
        top:    { row_net: R2 }
```

### Tableau récapitulatif — Outils et usages

| Objectif | Outil recommandé |
| --- | --- |
| Disposition logicielle (Windows) | MSKLC, AutoHotkey |
| Disposition logicielle (macOS) | Karabiner-Elements |
| Disposition logicielle (Linux) | Kalamine, XKB |
| Disposition multiplateforme | Keyman Developer |
| Conception physique du layout | Keyboard Layout Editor |
| Génération PCB automatisée | Ergogen |
| Firmware clavier standard | QMK, ZMK |
| Firmware sur-mesure (ce projet)  | Arduino-Pico |
| Microcontrôleur | RP2040-Zero |
| Conception PCB | KiCad |

---

## Ressources communautaires

| Ressource | Description |
| --- | --- |
| [awesome-keyboard (GitHub)](https://github.com/Delapouite/awesome-keyboard) | Liste curated d'outils, firmwares, guides et projets claviers |
| [r/MechanicalKeyboards](https://reddit.com/r/MechanicalKeyboards) | Communauté Reddit — retours d'expérience, DIY, layouts |
| [forum Bépo](https://forum.bepo.fr) | Forum francophone sur les layouts ergonomiques |
| [keeb.io](https://keeb.io/collections/keyboards) | Boutique et ressources pour claviers DIY |
| [CMKB — Communauté Colemak](https://colemak.com/) | Ressources et tutoriels Colemak |

---

> **Page précédente :** [05 — Analyse GPIO & Extension I2C](./05-analyse-gpio-extension.md)  
> **Page suivante :** [07 — Ressources & Références](./07-ressources-references.md)

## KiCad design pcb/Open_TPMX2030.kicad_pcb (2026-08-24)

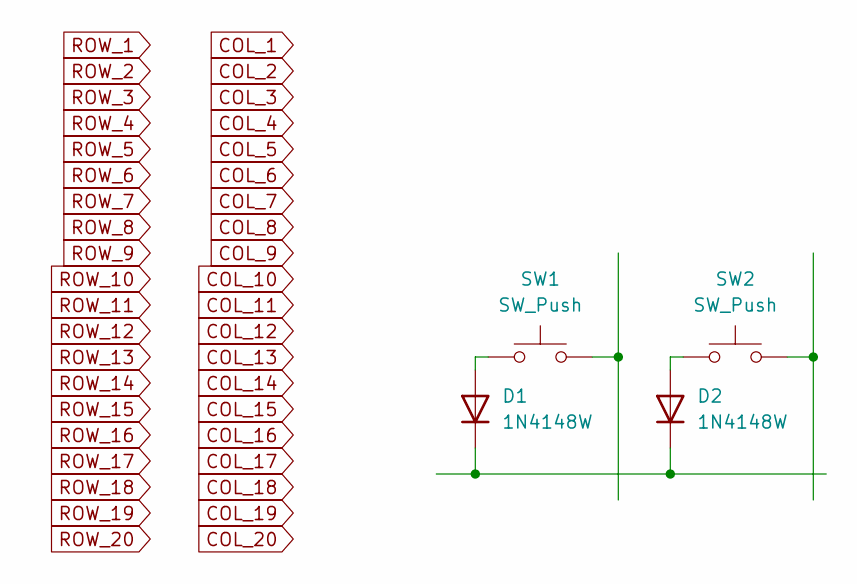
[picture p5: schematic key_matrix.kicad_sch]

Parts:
D1, D2: 1N4148W; D_SOD-123
SW1: SW_Push; SW_Hotswap_Kailh_Choc_V1V2_1.00u
SW2: SW_Push; SW_Hotswap_Kailh_MX_1.00u

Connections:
unnamed: D1.2 (A), SW1.1 (1_1)
unnamed: D1.1 (K), D2.1 (K)
unnamed: D2.2 (A), SW2.1 (1_1)

Board: 2 copper layers, 4 parts (0 on the bottom side), 3 nets, no tracks yet.

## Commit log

2026-08-16 feat: Add initial KiCad project files and documentation for Open-TPMX2030 keyboard
    [Open_TPMX2030.kicad_pcb, Open_TPMX2030.kicad_sch]
2026-08-17 feat: Adjusting the project for a successful start
    [Open_TPMX2030.kicad_pcb, Open_TPMX2030.kicad_sch, key_matrix.kicad_sch]
2026-08-24 feat: place two switch version for testing
    [Open_TPMX2030.kicad_pcb, key_matrix.kicad_sch]
